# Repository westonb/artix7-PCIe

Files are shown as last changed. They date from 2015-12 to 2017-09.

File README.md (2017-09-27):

# artix7-PCIe
Originally designed for a SDR expansion card. Design includes breakout header, 2 general purpose buttons, and a SFP cage. 

Optimized for OSHPark 4 layer fab and home assembly. 

Design has been built but prototypes were killed by JTAG ground loop due to user error. Further work not certain, but please fork and feel free to contact for support.

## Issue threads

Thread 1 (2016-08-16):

was this board built?

aholtzma, 2016-08-16:
I see you sent this board off to fab. Was it built? Did you need to make any changes to make it work?

theocean154, 2016-12-01:
Im also interested to know if this worked, im working on a very similar board, basically a stripped down AC701 with just the pcie, Ethernet, DDR, SD, and jtag, and could use your board as a reference.

theocean154, 2016-12-01:
https://oshpark.com/shared_projects/hLGqMXZK

westonb, 2016-12-11:
Board was built, before I could finish verifying everything I killed the FPGA with a JTAG ground loop. Future version I am going to add some buffers / protection on the JTAG lines. Have not had time to make more boards.

You are probably going to need to add more PCB layers for DRAM.

Closed 2016-12-11.

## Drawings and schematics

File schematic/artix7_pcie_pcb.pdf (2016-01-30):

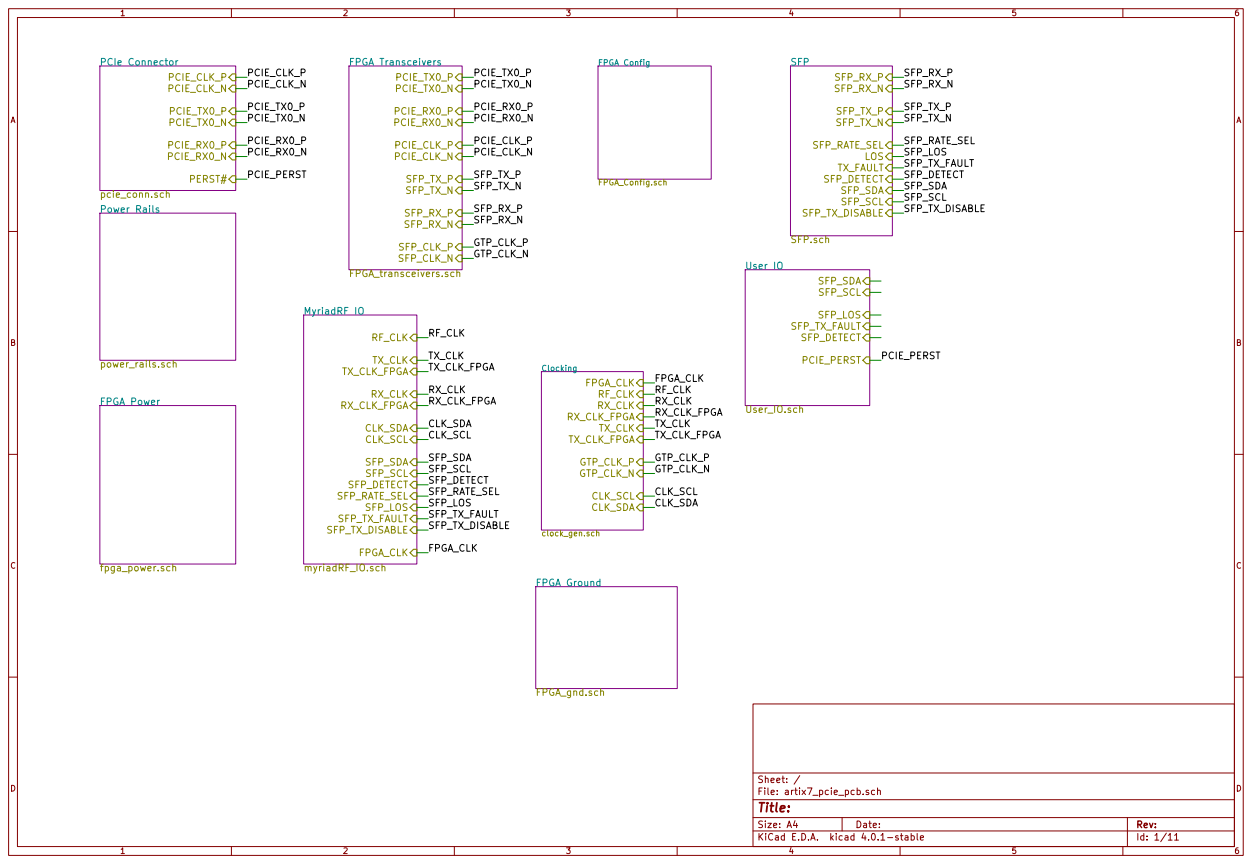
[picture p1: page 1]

PERST# Power Rails power_rails.sch
pcie_conn.sch

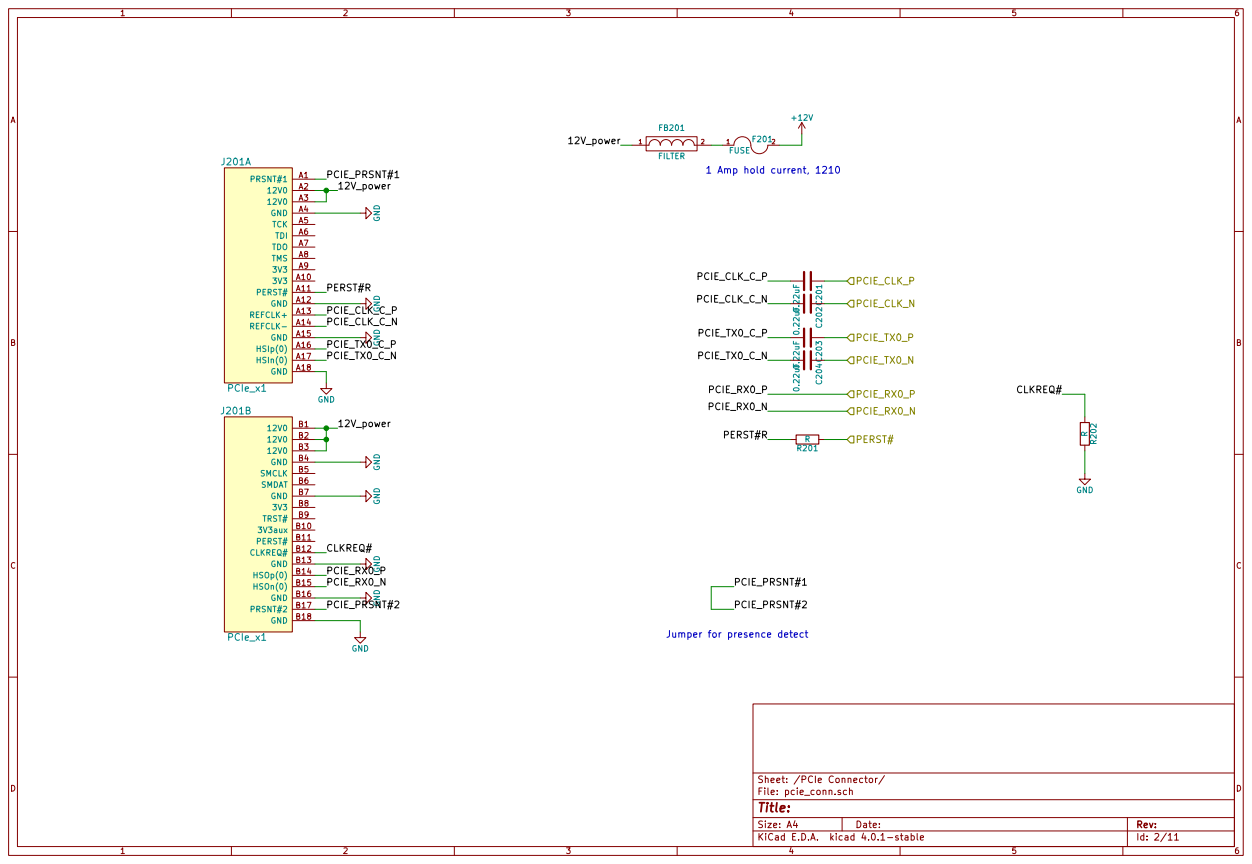
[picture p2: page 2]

File: pcie_conn.sch Sheet: /PCIe Connector/

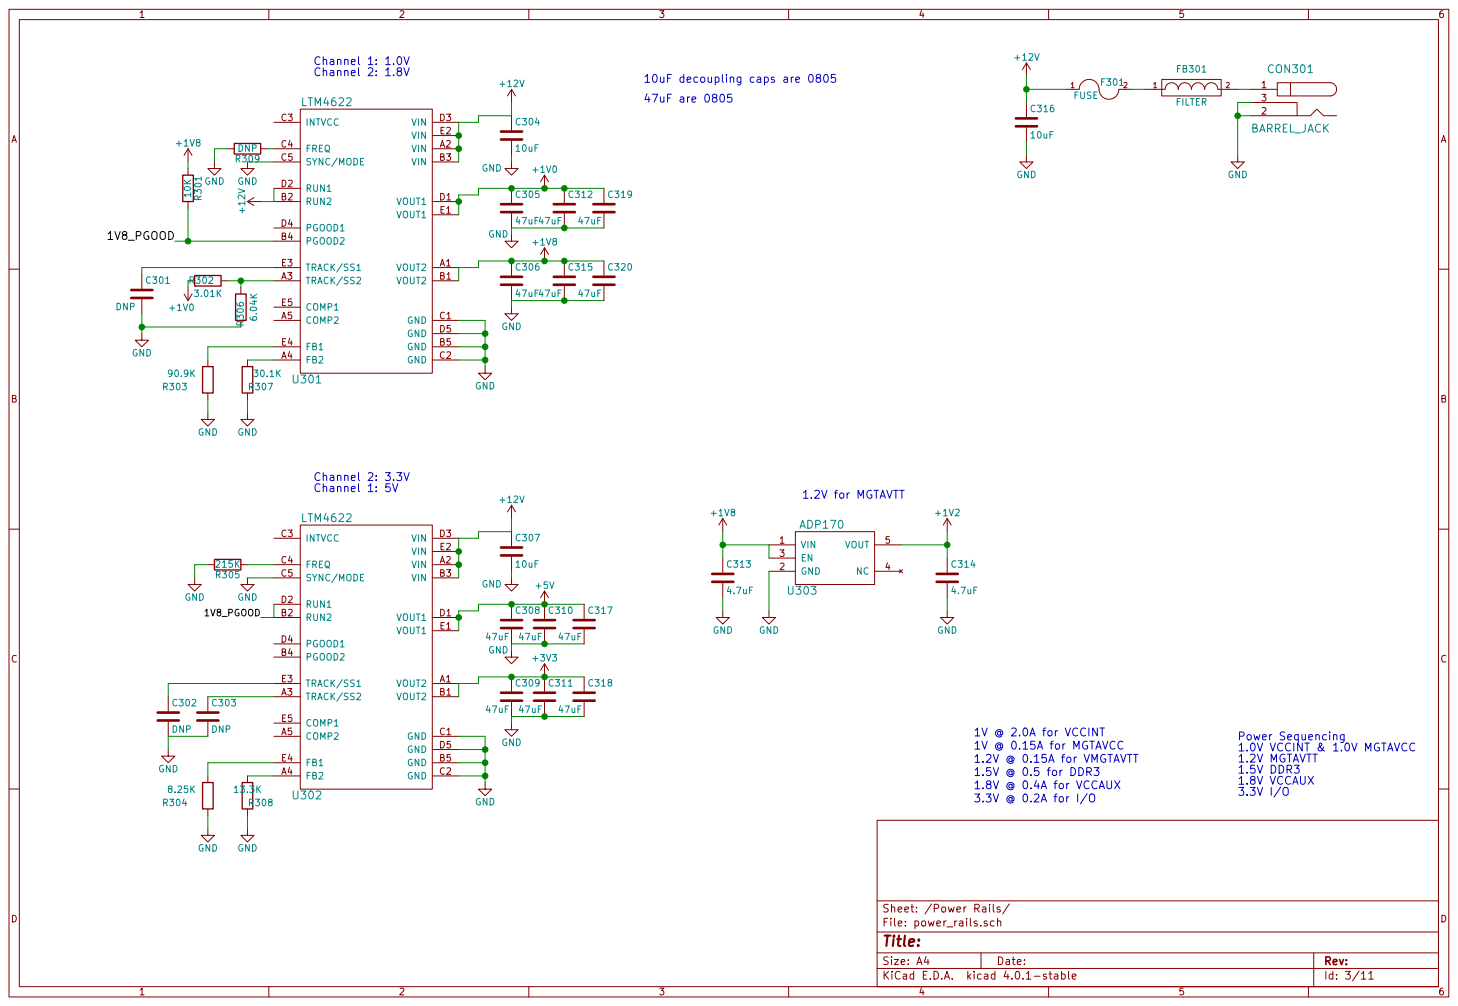
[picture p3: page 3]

File: power_rails.sch Sheet: /Power Rails/
Id: 3/11 Title:

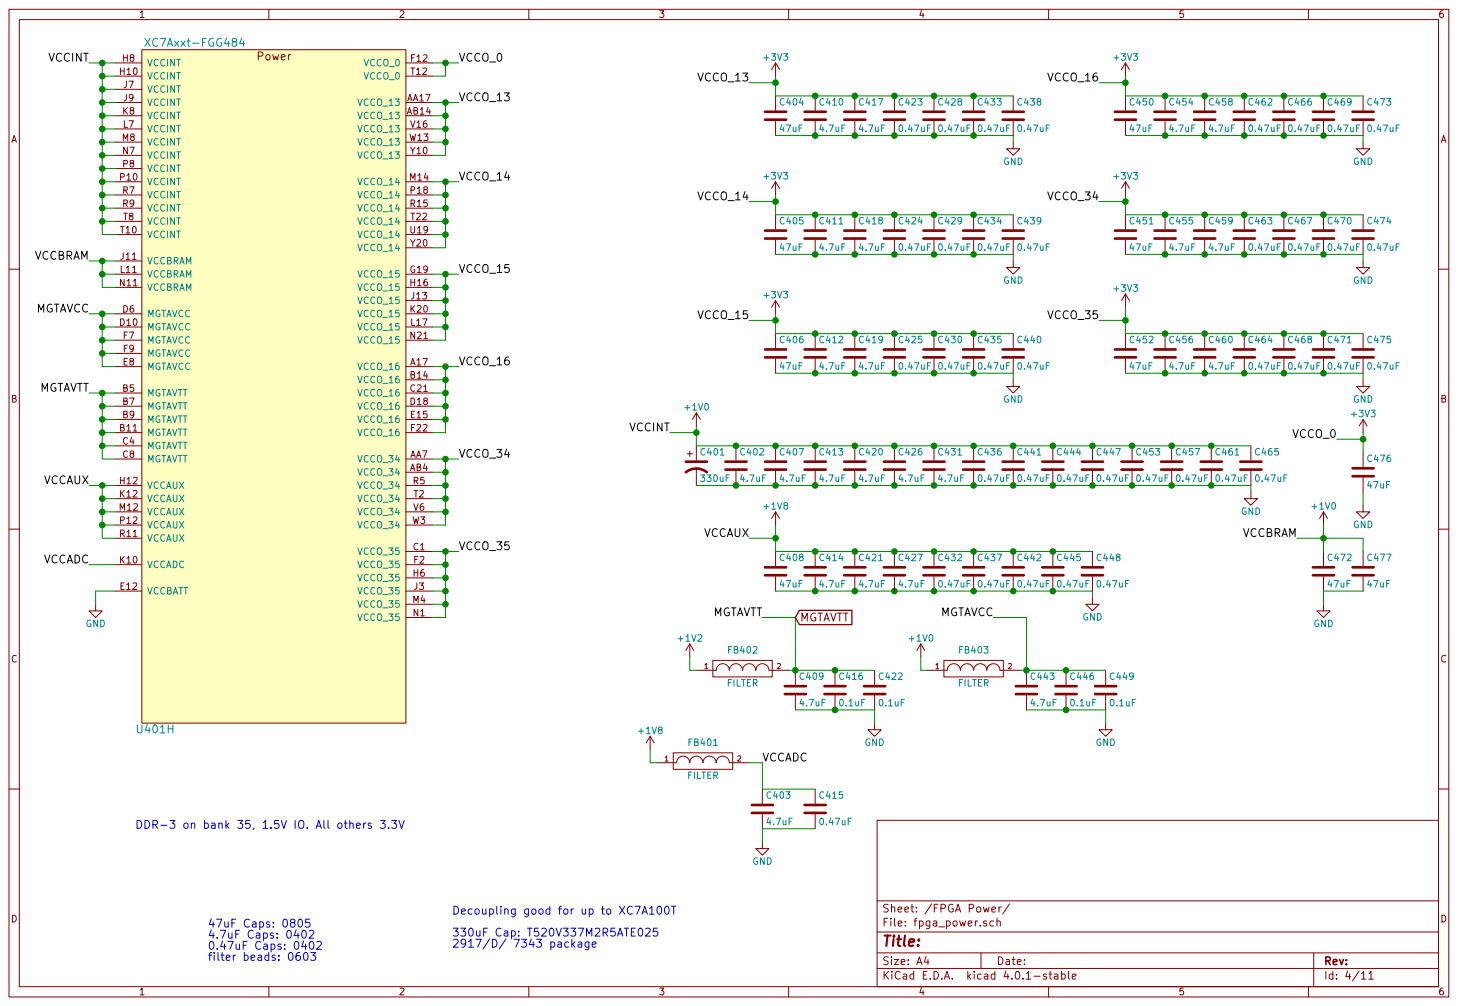
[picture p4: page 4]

0.47uF Decoupling good for up to XC7A100T

DDR-3 on bank 35, 1.5V IO. All others 3.3V

File: fpga_power.sch Sheet: /FPGA Power/
Id: 4/11 Title:

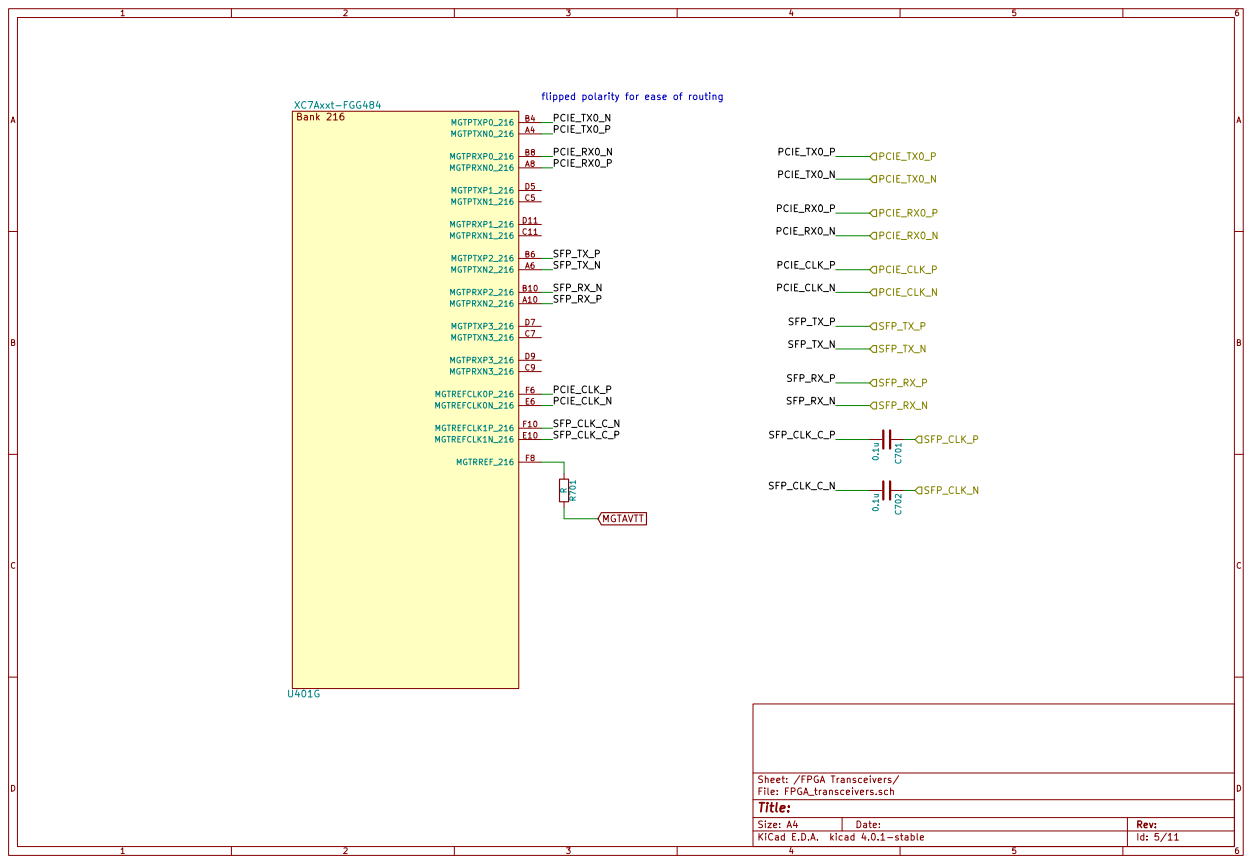
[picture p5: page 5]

flipped polarity for ease of routing

File: FPGA_transceivers.sch Sheet: /FPGA Transceivers/

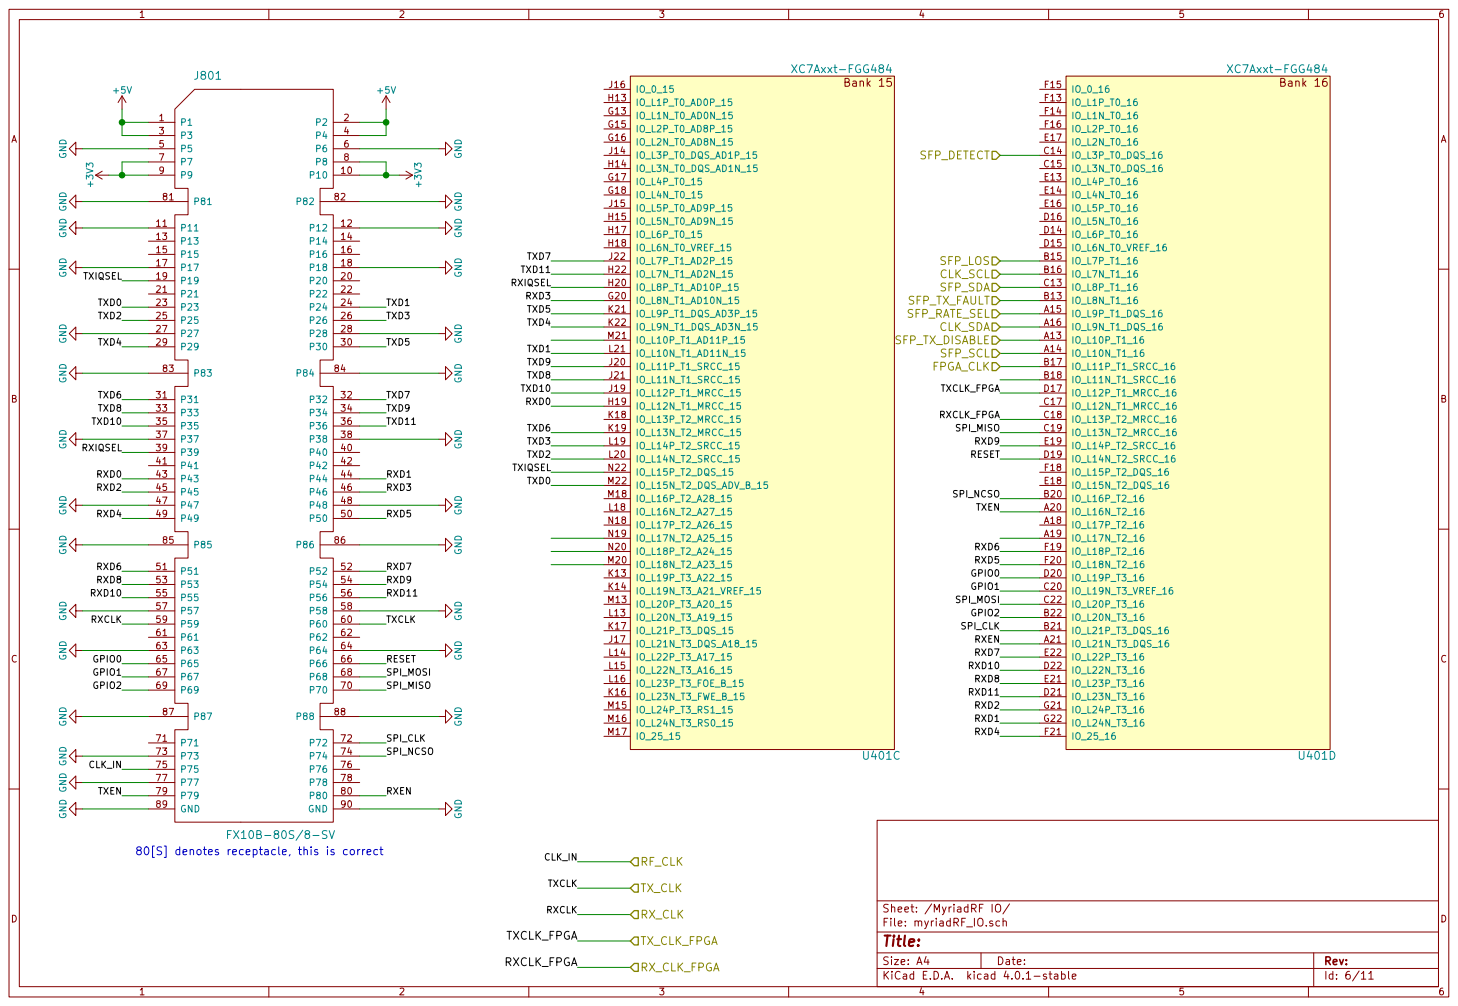
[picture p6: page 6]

80[S] denotes receptacle, this is correct

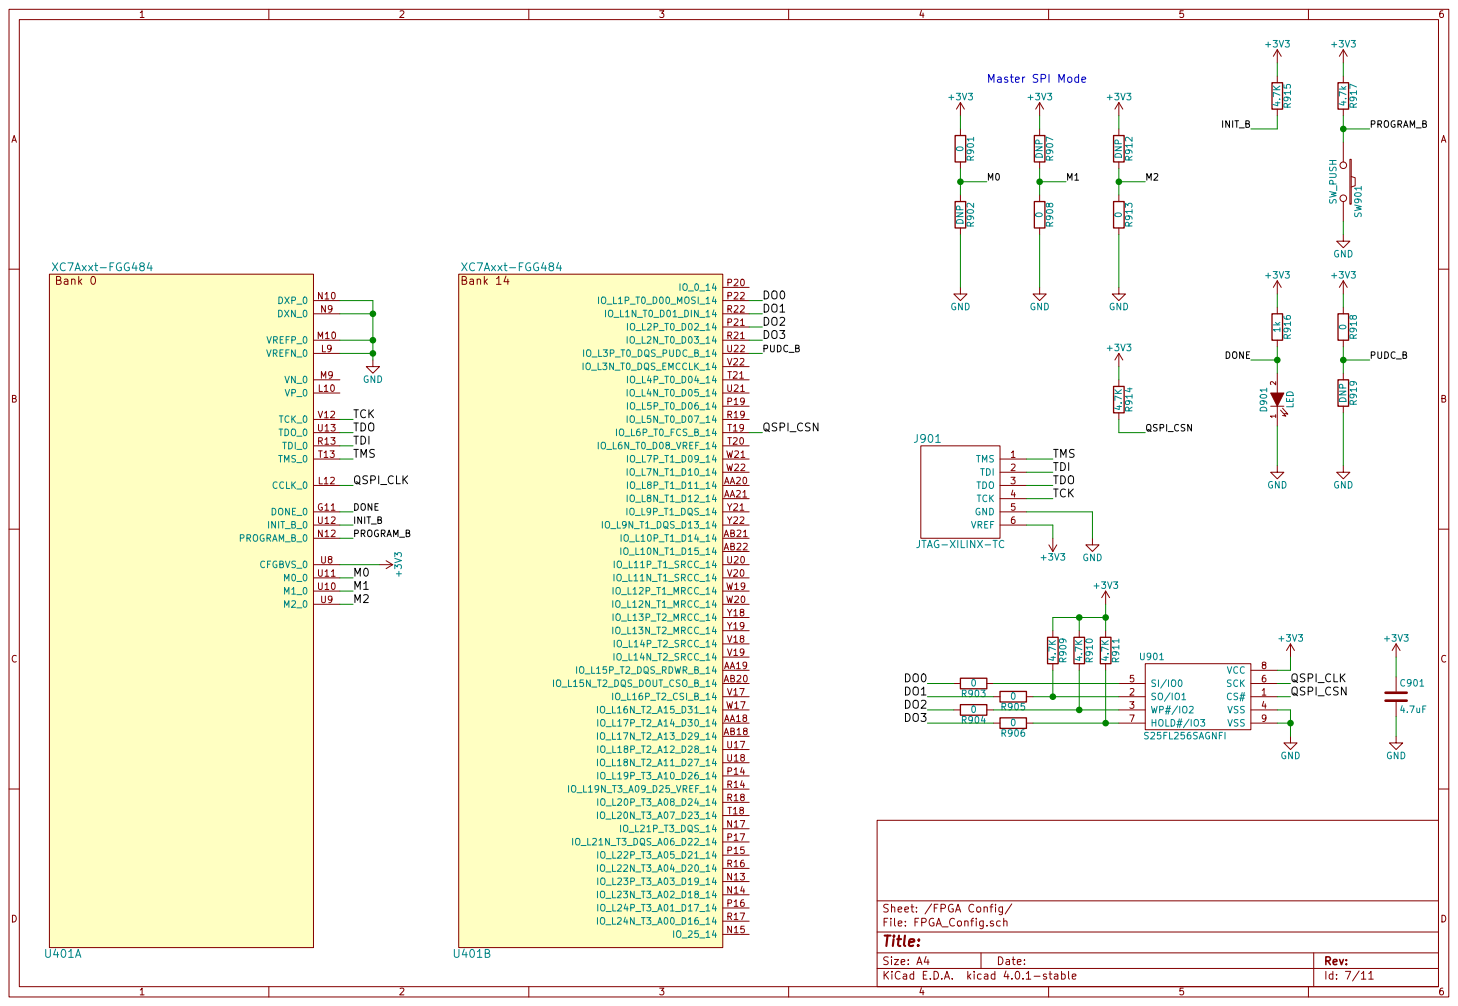
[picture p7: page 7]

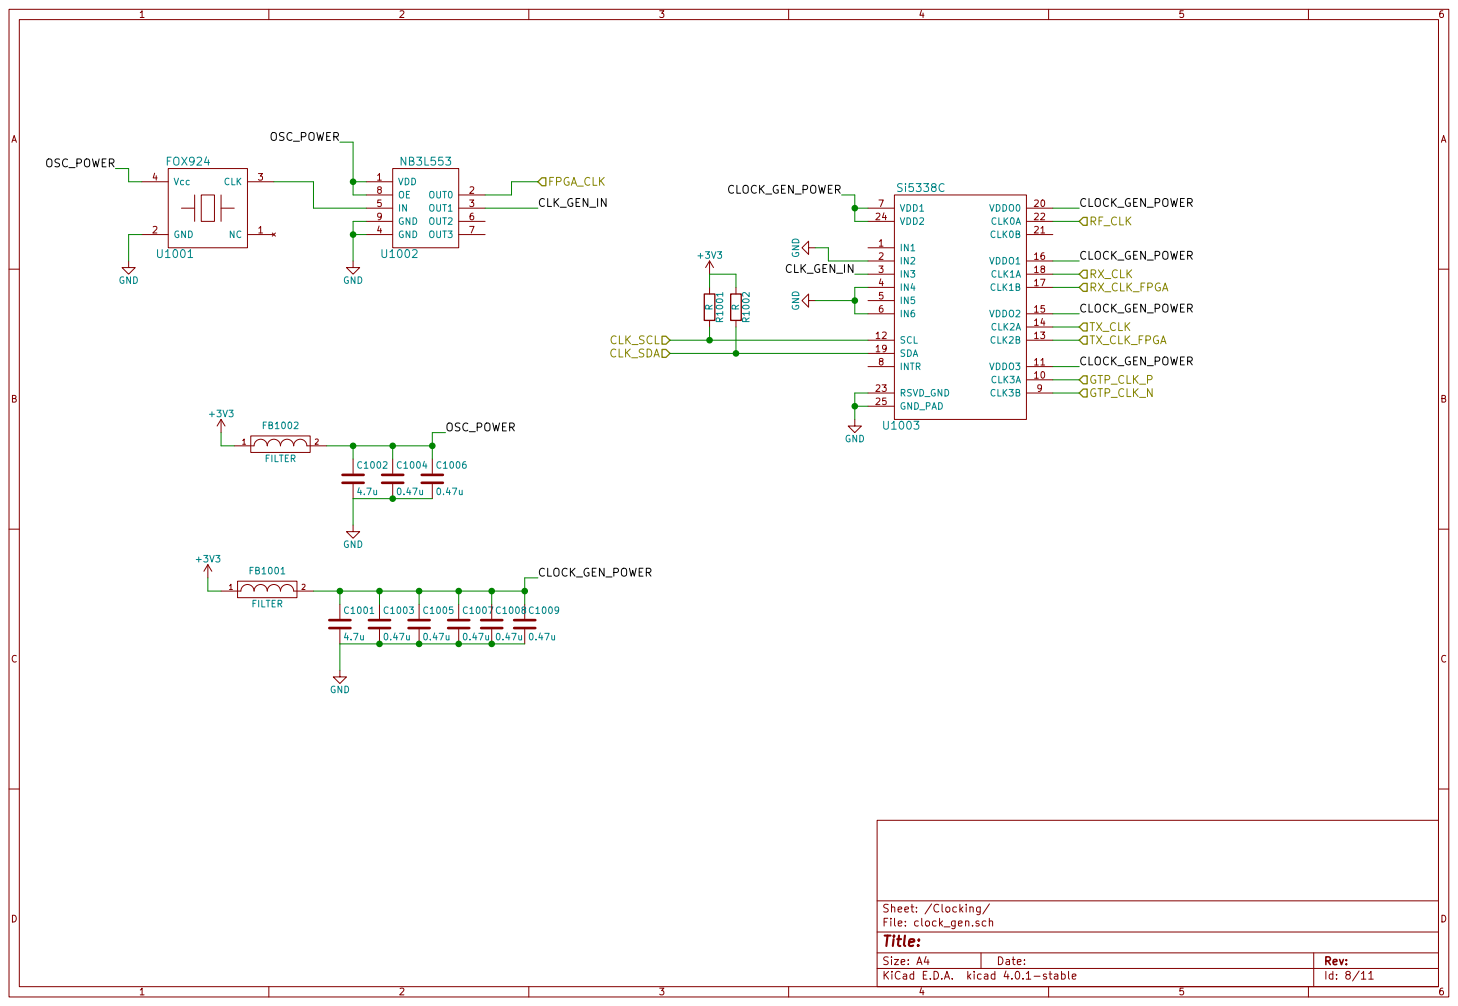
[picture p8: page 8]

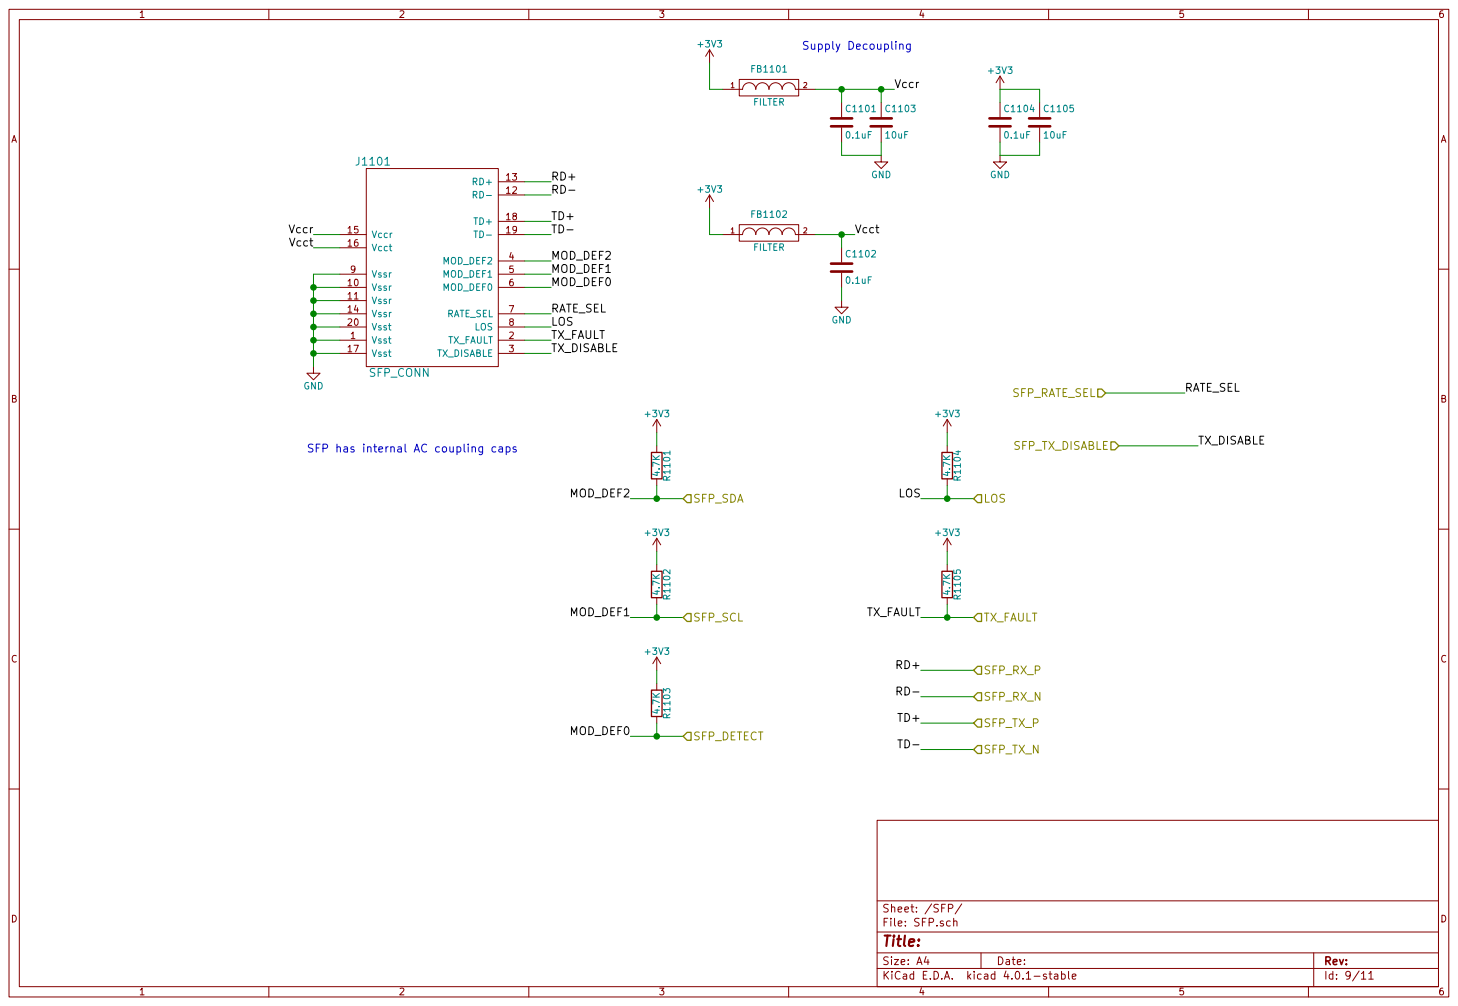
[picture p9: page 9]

Id: 9/11 Title: File: SFP.sch Sheet: /SFP/

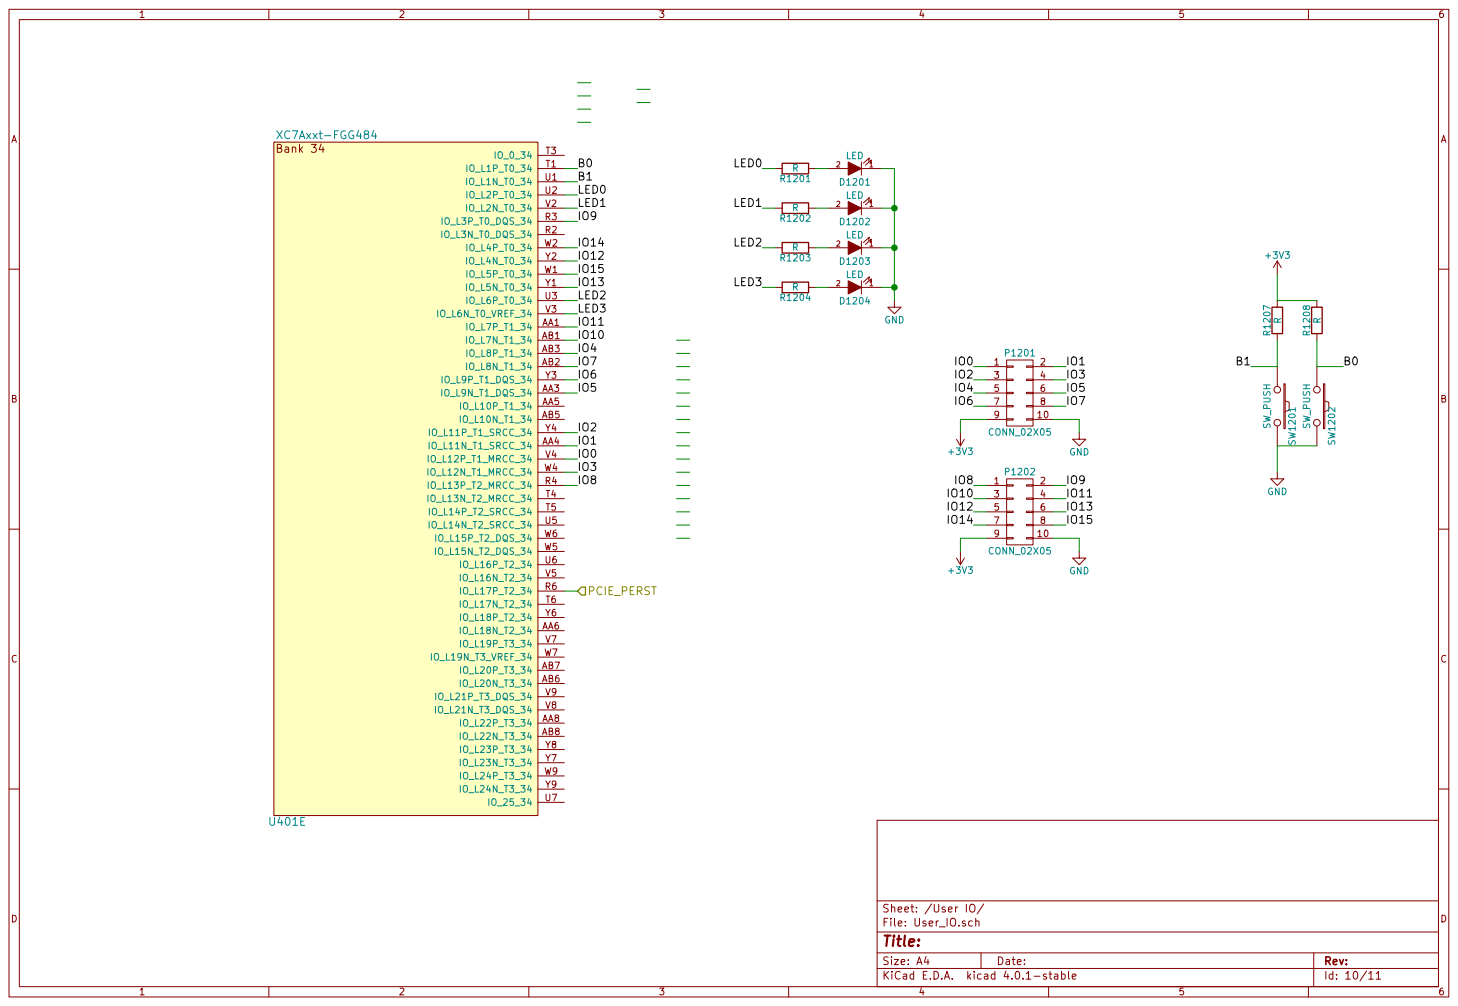
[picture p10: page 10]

File: User_IO.sch Sheet: /User IO/

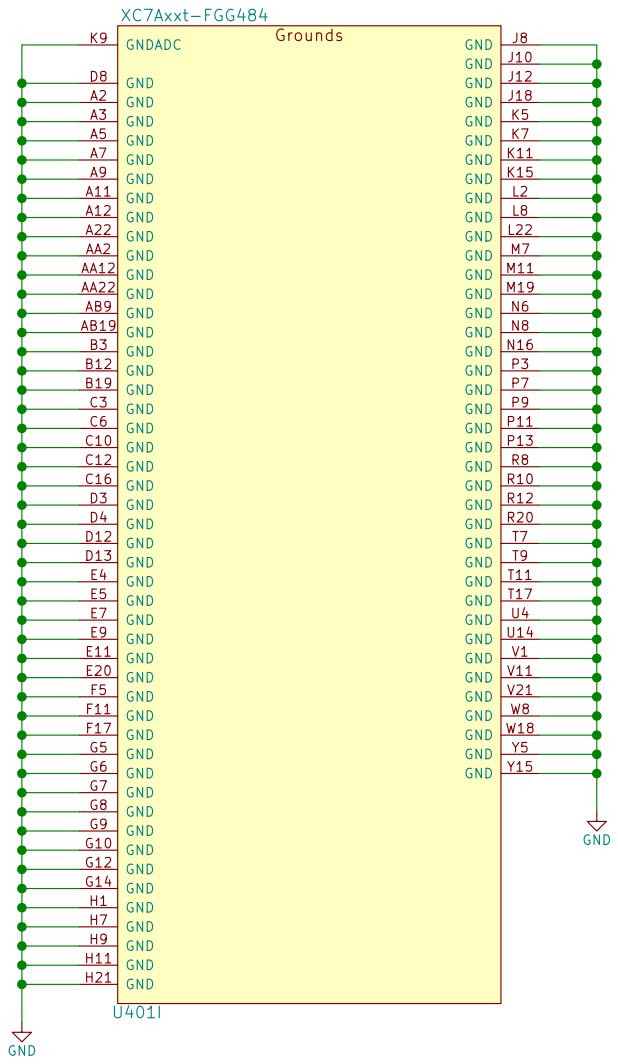
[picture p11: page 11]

File: FPGA_gnd.sch Sheet: /FPGA Ground/

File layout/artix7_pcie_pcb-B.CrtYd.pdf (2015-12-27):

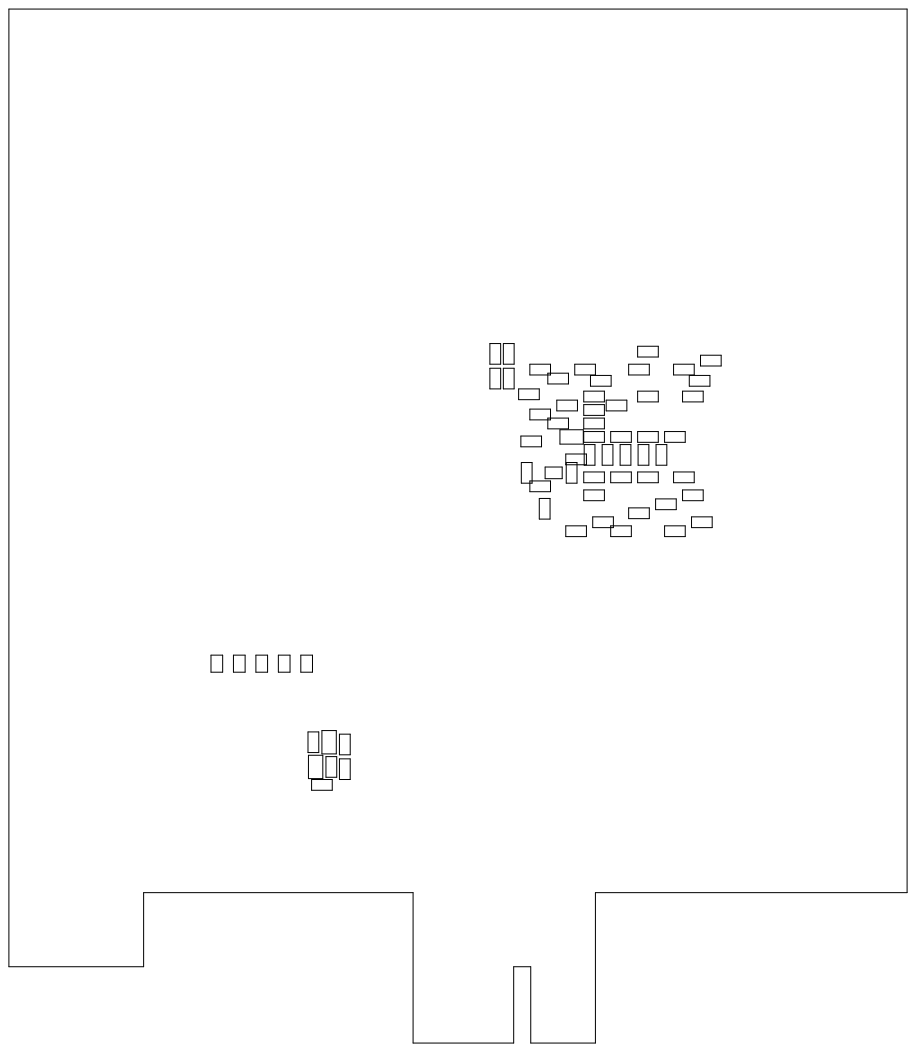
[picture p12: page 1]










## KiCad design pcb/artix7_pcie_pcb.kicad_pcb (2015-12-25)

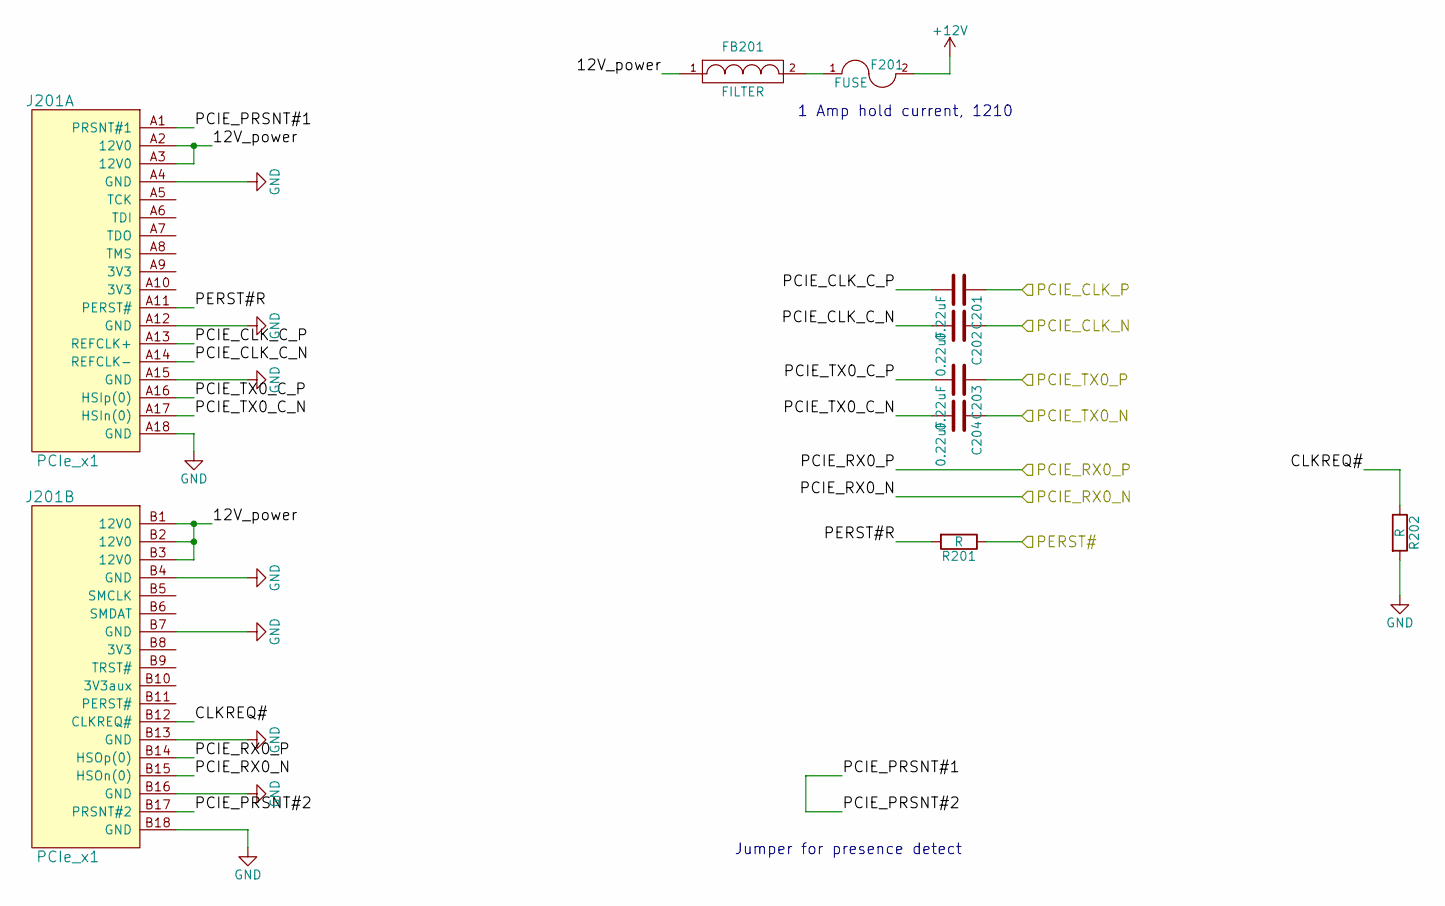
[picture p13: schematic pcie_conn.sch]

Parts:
C201, C202, C203, C204: 0.22uF; C_0402
F201: FUSE; SMD-0805
FB201: FILTER; L_0603
J201: PCIe_x1; PCIe_1x
R201, R202: R; R_0402

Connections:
+12V: F201.2; also elsewhere on the board
/FPGA Transceivers/PCIE_CLK_N: C202.1; also elsewhere on the board
/FPGA Transceivers/PCIE_CLK_P: C201.1; also elsewhere on the board
/FPGA Transceivers/PCIE_RX0_N: J201.B15 (HSOn(0)); also elsewhere on the board
/FPGA Transceivers/PCIE_RX0_P: J201.B14 (HSOp(0)); also elsewhere on the board
/FPGA Transceivers/PCIE_TX0_N: C204.1; also elsewhere on the board
/FPGA Transceivers/PCIE_TX0_P: C203.1; also elsewhere on the board
/PCIe Connector/12V_power: FB201.1, J201.A2 (12V0), J201.A3 (12V0), J201.B1 (12V0), J201.B2 (12V0), J201.B3 (12V0)
/PCIe Connector/CLKREQ#: J201.B12 (CLKREQ#), R202.1
/PCIe Connector/PCIE_CLK_C_N: C202.2, J201.A14 (REFCLK-)
/PCIe Connector/PCIE_CLK_C_P: C201.2, J201.A13 (REFCLK+)
/PCIe Connector/PCIE_PRSNT#1: J201.A1 (PRSNT#1), J201.B17 (PRSNT#2)
/PCIe Connector/PCIE_TX0_C_N: C204.2, J201.A17 (HSIn(0))
/PCIe Connector/PCIE_TX0_C_P: C203.2, J201.A16 (HSIp(0))
/PCIe Connector/PERST#R: J201.A11 (PERST#), R201.2
/User IO/PCIE_PERST: R201.1; also elsewhere on the board
GND: J201.A4 (GND), J201.A12 (GND), J201.A15 (GND), J201.A18 (GND), J201.B4 (GND), J201.B7 (GND), J201.B13 (GND), J201.B16 (GND), J201.B18 (GND), R202.2; also elsewhere on the board
unnamed: F201.1, FB201.2

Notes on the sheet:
Jumper for presence detect
1 Amp hold current, 1210

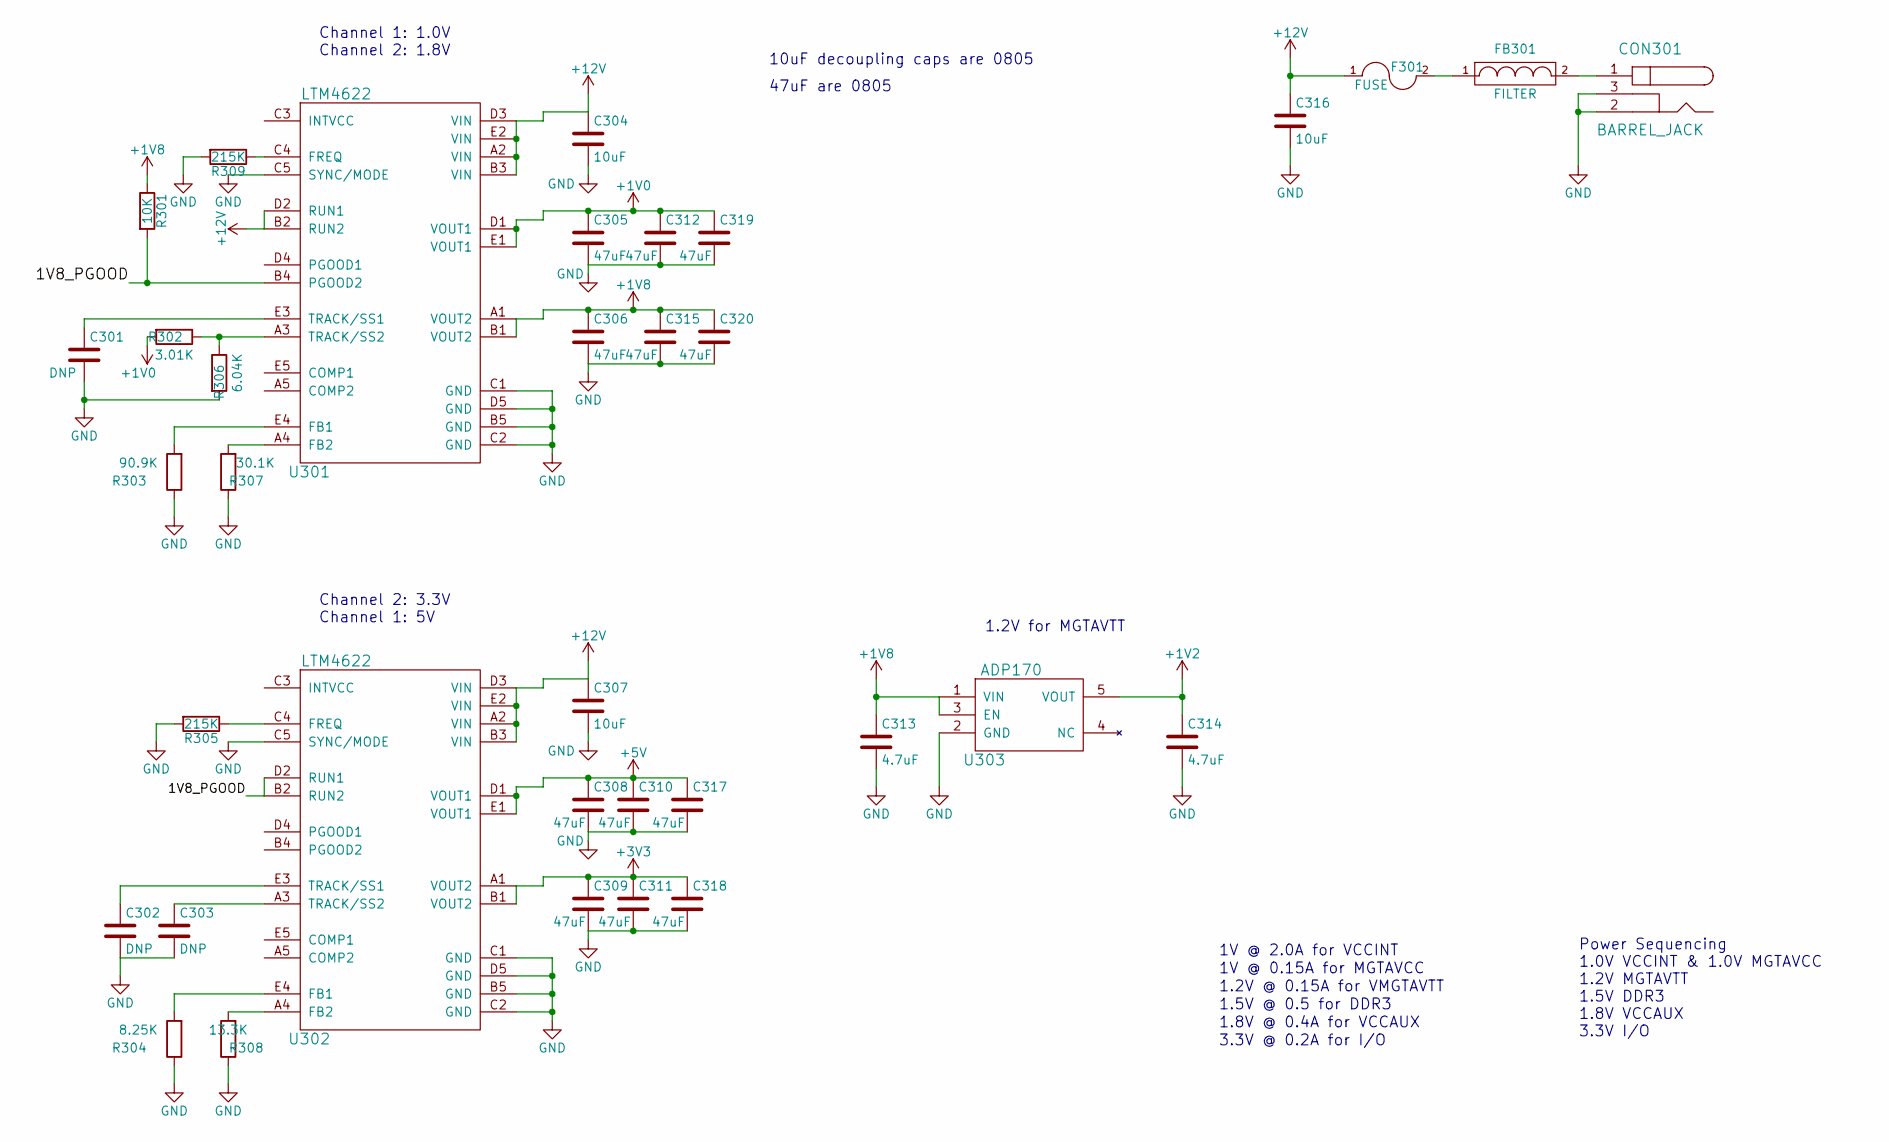
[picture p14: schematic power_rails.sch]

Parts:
C301, C302, C303: DNP; C_0402
C304, C307, C316: 10uF; C_0805
C305, C306, C308, C309, C310, C311, C312, C315, C317, C318, C319, C320: 47uF; C_0805
C313, C314: 4.7uF; C_0402
CON301: BARREL_JACK; DC_2.1mm_PJ-202A
F301: FUSE; SMD-0805
FB301: FILTER; L_0603
R301: 10K; R_0402
R302: 3.01K; R_0402
R303: 90.9K; R_0402
R304: 8.25K; R_0402
R305, R309: 215K; R_0402
R306: 6.04K; R_0402
R307: 30.1K; R_0402
R308: 13.3K; R_0402
U301, U302: LTM4622; LGA25_6_25x6_25
U303: ADP170; TSOT-23-5

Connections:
+1V0: C305.1, C312.1, C319.1, R302.2, U301.D1 (VOUT1), U301.E1 (VOUT1); also elsewhere on the board
+1V2: C314.1, U303.5 (VOUT); also elsewhere on the board
+1V8: C306.1, C313.1, C315.1, C320.1, R301.1, U301.A1 (VOUT2), U301.B1 (VOUT2), U303.1 (VIN), U303.3 (EN); also elsewhere on the board
+3V3: C309.1, C311.1, C318.1, U302.A1 (VOUT2), U302.B1 (VOUT2); also elsewhere on the board
+5V: C308.1, C310.1, C317.1, U302.D1 (VOUT1), U302.E1 (VOUT1); also elsewhere on the board
+12V: C304.1, C307.1, C316.1, F301.1, U301.A2 (VIN), U301.B2 (RUN2), U301.B3 (VIN), U301.D2 (RUN1), U301.D3 (VIN), U301.E2 (VIN), U302.A2 (VIN), U302.B3 (VIN), U302.D3 (VIN), U302.E2 (VIN); also elsewhere on the board
/Power Rails/1V8_PGOOD: R301.2, U301.B4 (PGOOD2), U302.B2 (RUN2), U302.D2 (RUN1)
GND: C301.2, C302.2, C303.2, C304.2, C305.2, C306.2, C307.2, C308.2, C309.2, C310.2, C311.2, C312.2, C313.2, C314.2, C315.2, C316.2, C317.2, C318.2, C319.2, C320.2, CON301.2, CON301.3, R303.1, R304.1, R305.2, R306.2, R307.1, R308.1, R309.2, U301.B5 (GND), U301.C1 (GND), U301.C2 (GND), U301.C5 (SYNC/MODE), U301.D5 (GND), U302.B5 (GND), U302.C1 (GND), U302.C2 (GND), U302.C5 (SYNC/MODE), U302.D5 (GND), U303.2 (GND); also elsewhere on the board
unnamed: C301.1, U301.E3 (TRACK/SS1)
unnamed: C302.1, U302.E3 (TRACK/SS1)
unnamed: C303.1, U302.A3 (TRACK/SS2)
unnamed: CON301.1, FB301.2
unnamed: F301.2, FB301.1
unnamed: R302.1, R306.1, U301.A3 (TRACK/SS2)
unnamed: R303.2, U301.E4 (FB1)
unnamed: R304.2, U302.E4 (FB1)
unnamed: R305.1, U302.C4 (FREQ)
unnamed: R307.2, U301.A4 (FB2)
unnamed: R308.2, U302.A4 (FB2)
unnamed: R309.1, U301.C4 (FREQ)

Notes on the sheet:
1.5V @ 0.5 for DDR3
1V @ 2.0A for VCCINT
1.2V @ 0.15A for VMGTAVTT
1.8V @ 0.4A for VCCAUX
3.3V @ 0.2A for I/O
1V @ 0.15A for MGTAVCC
Power Sequencing 1.0V VCCINT & 1.0V MGTAVCC 1.2V MGTAVTT 1.5V DDR3 1.8V VCCAUX 3.3V I/O
Channel 1: 1.0V Channel 2: 1.8V
1.2V for MGTAVTT
Channel 2: 3.3V Channel 1: 5V
10uF decoupling caps are 0805
47uF are 0805

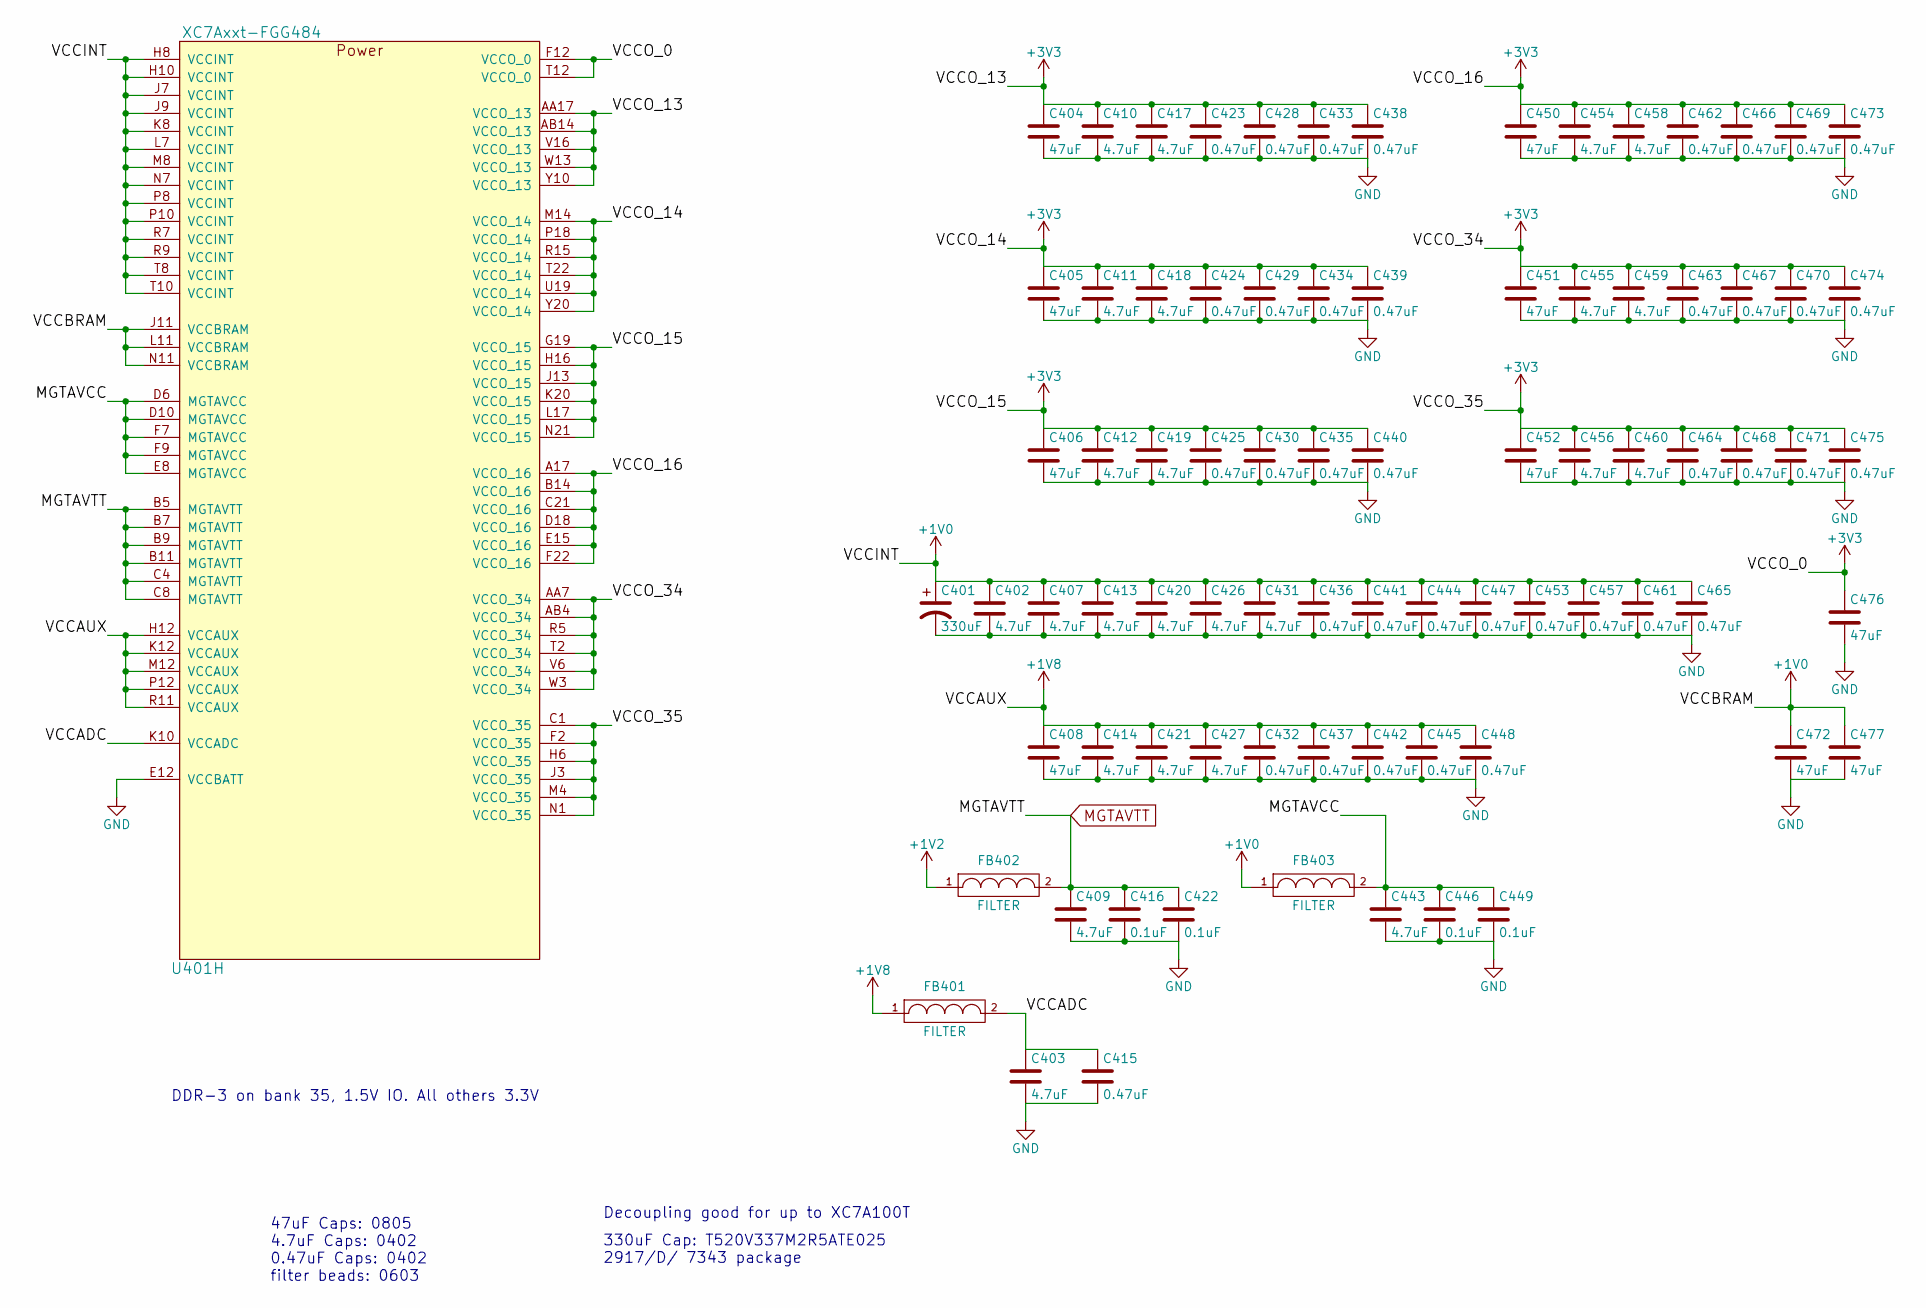
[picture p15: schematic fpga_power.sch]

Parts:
C401: 330uF; TantalC_SizeD_EIA-7343
C402, C403, C407, C409, C410, C411, C412, C413, C414, C417, C418, C419, C420, C421, C426, C427, C431, C443, C454, C455, C456, C458, C459, C460: 4.7uF; 0402_in_grid
C404, C405, C406, C408, C450, C451, C452, C472, C476, C477: 47uF; C_0805
C415, C423, C424, C425, C428, C429, C430, C432, C433, C434, C435, C436, C437, C438, C439, C440, C441, C442, C444, C445, C447, C448, C453, C457, C461, C462, C463, C464, C465, C466, C467, C468, C469, C470, C471, C473, C474, C475: 0.47uF; 0402_in_grid
C416, C422, C446, C449: 0.1uF; 0402_in_grid
FB401, FB402, FB403: FILTER; L_0603
U401: XC7Axxt-FGG484; BGA_484_22x22_FULLARRAY_1MM

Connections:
+1V0: C401.1, C402.1, C407.1, C413.1, C420.1, C426.1, C431.1, C436.1, C441.1, C444.1, C447.1, C453.1, C457.1, C461.1, C465.1, C472.1, C477.1, FB403.1, U401.H8 (VCCINT), U401.H10 (VCCINT), U401.J7 (VCCINT), U401.J9 (VCCINT), U401.J11 (VCCBRAM), U401.K8 (VCCINT), U401.L7 (VCCINT), U401.L11 (VCCBRAM), U401.M8 (VCCINT), U401.N7 (VCCINT), U401.N11 (VCCBRAM), U401.P8 (VCCINT), U401.P10 (VCCINT), U401.R7 (VCCINT), U401.R9 (VCCINT), U401.T8 (VCCINT), U401.T10 (VCCINT); also elsewhere on the board
+1V2: FB402.1; also elsewhere on the board
+1V8: C408.1, C414.1, C421.1, C427.1, C432.1, C437.1, C442.1, C445.1, C448.1, FB401.1, U401.H12 (VCCAUX), U401.K12 (VCCAUX), U401.M12 (VCCAUX), U401.P12 (VCCAUX), U401.R11 (VCCAUX); also elsewhere on the board
+3V3: C404.1, C405.1, C406.1, C410.1, C411.1, C412.1, C417.1, C418.1, C419.1, C423.1, C424.1, C425.1, C428.1, C429.1, C430.1, C433.1, C434.1, C435.1, C438.1, C439.1, C440.1, C450.1, C451.1, C452.1, C454.1, C455.1, C456.1, C458.1, C459.1, C460.1, C462.1, C463.1, C464.1, C466.1, C467.1, C468.1, C469.1, C470.1, C471.1, C473.1, C474.1, C475.1, C476.1, U401.A17 (VCCO_16), U401.AA7 (VCCO_34), U401.AA17 (VCCO_13), U401.AB4 (VCCO_34), U401.AB14 (VCCO_13), U401.B14 (VCCO_16), U401.C1 (VCCO_35), U401.C21 (VCCO_16), U401.D18 (VCCO_16), U401.E15 (VCCO_16), U401.F2 (VCCO_35), U401.F12 (VCCO_0), U401.F22 (VCCO_16), U401.G19 (VCCO_15), U401.H6 (VCCO_35), U401.H16 (VCCO_15), U401.J3 (VCCO_35), U401.J13 (VCCO_15), U401.K20 (VCCO_15), U401.L17 (VCCO_15), U401.M4 (VCCO_35), U401.M14 (VCCO_14), U401.N1 (VCCO_35), U401.N21 (VCCO_15), U401.P18 (VCCO_14), U401.R5 (VCCO_34), U401.R15 (VCCO_14), U401.T2 (VCCO_34), U401.T12 (VCCO_0), U401.T22 (VCCO_14), U401.U19 (VCCO_14), U401.V6 (VCCO_34), U401.V16 (VCCO_13), U401.W3 (VCCO_34), U401.W13 (VCCO_13), U401.Y10 (VCCO_13), U401.Y20 (VCCO_14); also elsewhere on the board
/FPGA Power/MGTAVCC: C443.1, C446.1, C449.1, FB403.2, U401.D6 (MGTAVCC), U401.D10 (MGTAVCC), U401.E8 (MGTAVCC), U401.F7 (MGTAVCC), U401.F9 (MGTAVCC)
/FPGA Power/VCCADC: C403.1, C415.1, FB401.2, U401.K10 (VCCADC)
GND: C401.2, C402.2, C403.2, C404.2, C405.2, C406.2, C407.2, C408.2, C409.2, C410.2, C411.2, C412.2, C413.2, C414.2, C415.2, C416.2, C417.2, C418.2, C419.2, C420.2, C421.2, C422.2, C423.2, C424.2, C425.2, C426.2, C427.2, C428.2, C429.2, C430.2, C431.2, C432.2, C433.2, C434.2, C435.2, C436.2, C437.2, C438.2, C439.2, C440.2, C441.2, C442.2, C443.2, C444.2, C445.2, C446.2, C447.2, C448.2, C449.2, C450.2, C451.2, C452.2, C453.2, C454.2, C455.2, C456.2, C457.2, C458.2, C459.2, C460.2, C461.2, C462.2, C463.2, C464.2, C465.2, C466.2, C467.2, C468.2, C469.2, C470.2, C471.2, C472.2, C473.2, C474.2, C475.2, C476.2, C477.2, U401.E12 (VCCBATT); also elsewhere on the board
MGTAVTT: C409.1, C416.1, C422.1, FB402.2, U401.B5 (MGTAVTT), U401.B7 (MGTAVTT), U401.B9 (MGTAVTT), U401.B11 (MGTAVTT), U401.C4 (MGTAVTT), U401.C8 (MGTAVTT); also elsewhere on the board

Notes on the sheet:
DDR-3 on bank 35, 1.5V IO. All others 3.3V
47uF Caps: 0805 4.7uF Caps: 0402 0.47uF Caps: 0402 filter beads: 0603
Decoupling good for up to XC7A100T
330uF Cap: T520V337M2R5ATE025 2917/D/ 7343 package

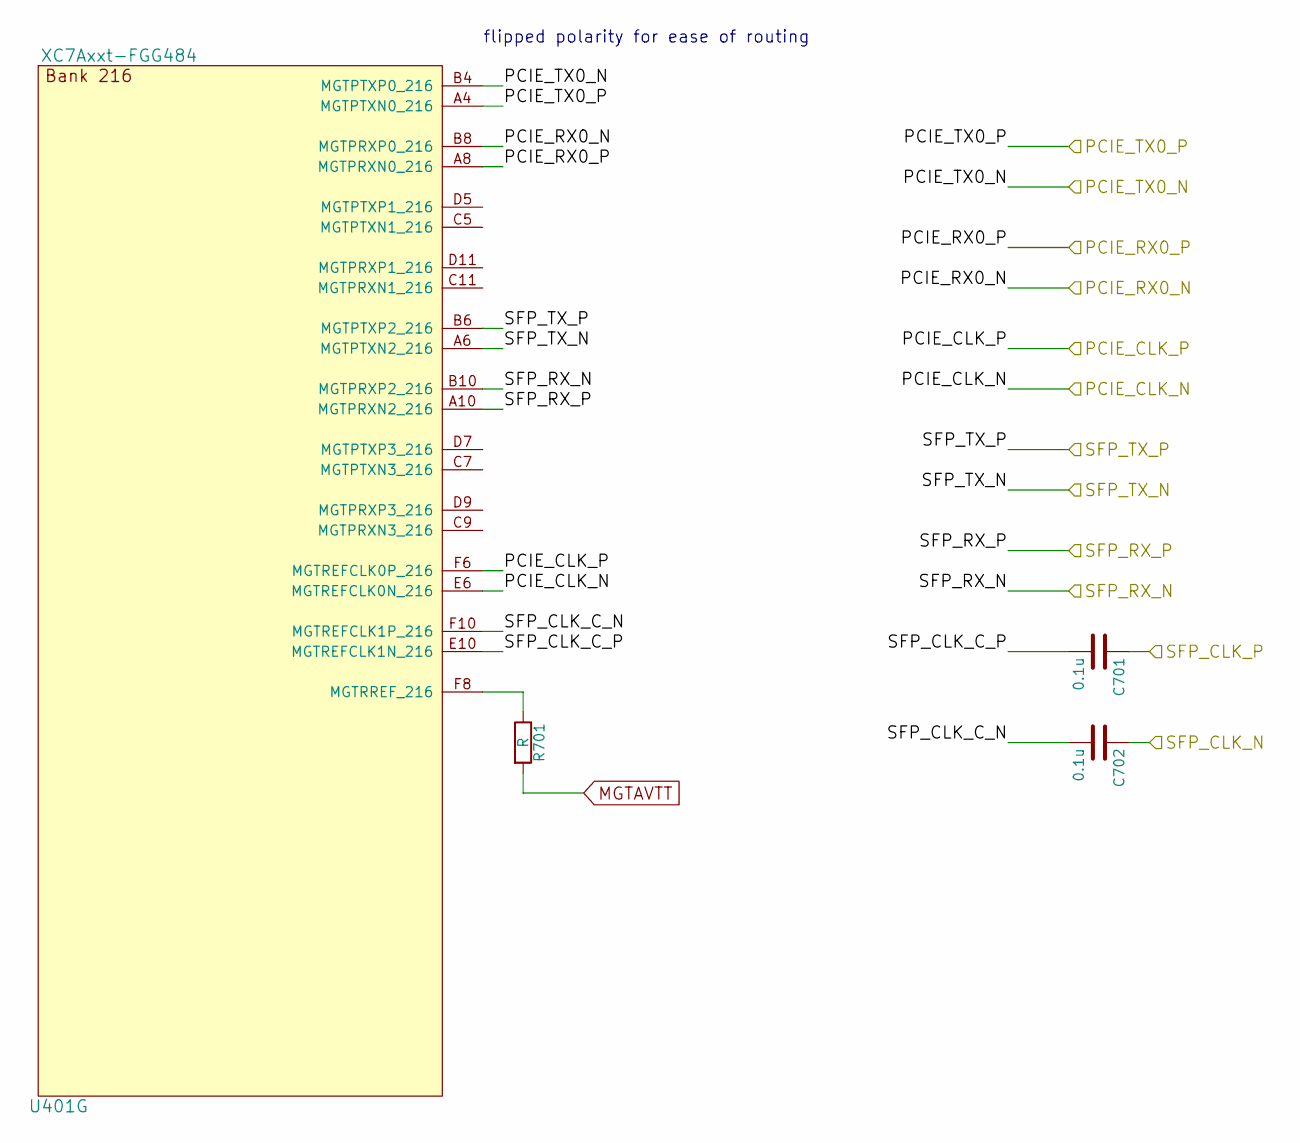
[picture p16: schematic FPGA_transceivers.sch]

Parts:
C701, C702: 0.1u; C_0402
R701: R; R_0402
U401: XC7Axxt-FGG484; BGA_484_22x22_FULLARRAY_1MM

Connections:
/Clocking/GTP_CLK_N: C702.1; also elsewhere on the board
/Clocking/GTP_CLK_P: C701.1; also elsewhere on the board
/FPGA Transceivers/PCIE_CLK_N: U401.E6 (MGTREFCLK0N_216); also elsewhere on the board
/FPGA Transceivers/PCIE_CLK_P: U401.F6 (MGTREFCLK0P_216); also elsewhere on the board
/FPGA Transceivers/PCIE_RX0_N: U401.B8 (MGTPRXP0_216); also elsewhere on the board
/FPGA Transceivers/PCIE_RX0_P: U401.A8 (MGTPRXN0_216); also elsewhere on the board
/FPGA Transceivers/PCIE_TX0_N: U401.B4 (MGTPTXP0_216); also elsewhere on the board
/FPGA Transceivers/PCIE_TX0_P: U401.A4 (MGTPTXN0_216); also elsewhere on the board
/FPGA Transceivers/SFP_CLK_C_N: C702.2, U401.F10 (MGTREFCLK1P_216)
/FPGA Transceivers/SFP_CLK_C_P: C701.2, U401.E10 (MGTREFCLK1N_216)
/FPGA Transceivers/SFP_RX_N: U401.B10 (MGTPRXP2_216); also elsewhere on the board
/FPGA Transceivers/SFP_RX_P: U401.A10 (MGTPRXN2_216); also elsewhere on the board
/FPGA Transceivers/SFP_TX_N: U401.A6 (MGTPTXN2_216); also elsewhere on the board
/FPGA Transceivers/SFP_TX_P: U401.B6 (MGTPTXP2_216); also elsewhere on the board
MGTAVTT: R701.2; also elsewhere on the board
unnamed: R701.1, U401.F8 (MGTRREF_216)

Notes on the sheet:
flipped polarity for ease of routing

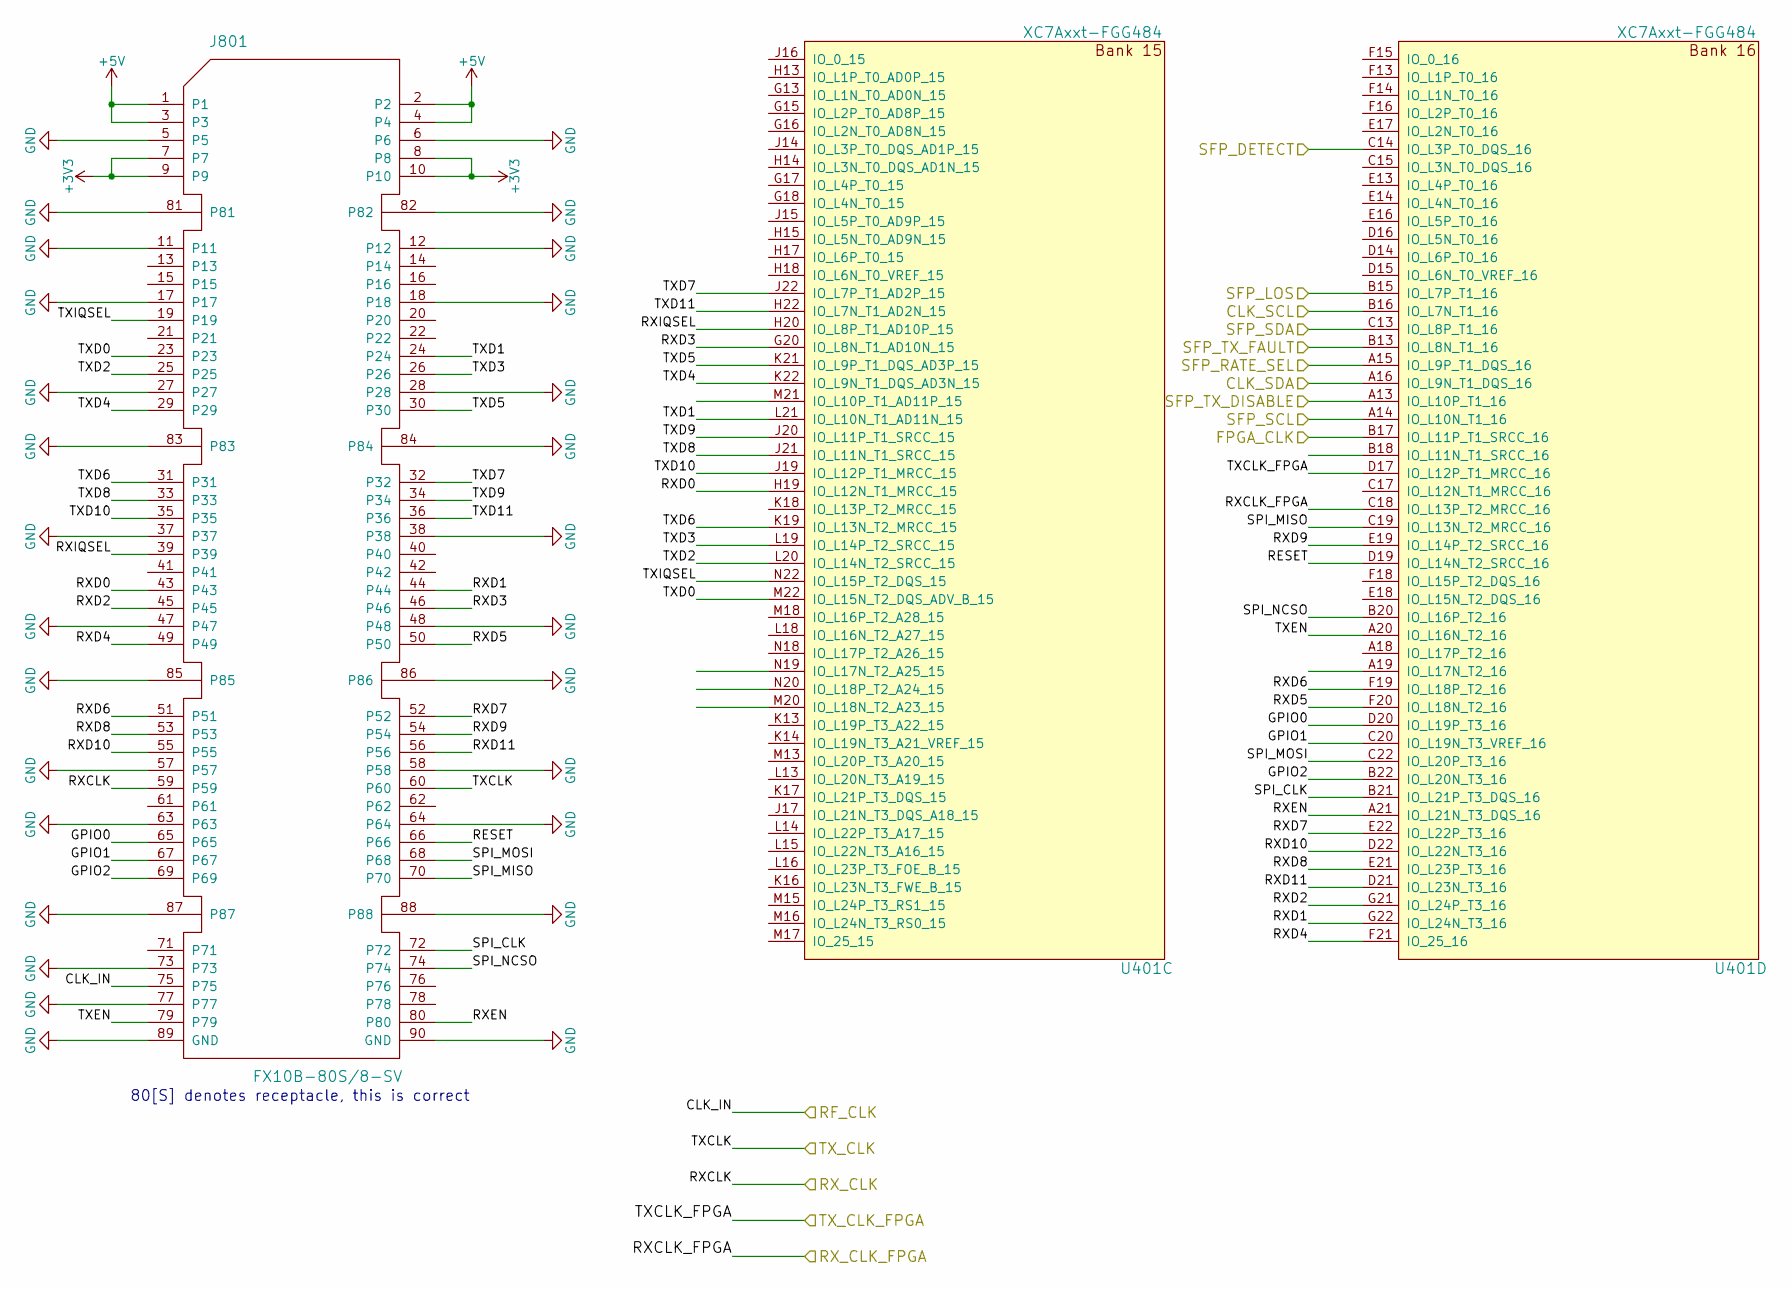
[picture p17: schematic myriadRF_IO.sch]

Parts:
J801: FX10B-80S/8-SV; FX10B_80S_8_SV
U401: XC7Axxt-FGG484; BGA_484_22x22_FULLARRAY_1MM

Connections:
+3V3: J801.7, J801.8, J801.9, J801.10; also elsewhere on the board
+5V: J801.1, J801.2, J801.3, J801.4; also elsewhere on the board
/Clocking/CLK_SCL: U401.B16 (IO_L7N_T1_16); also elsewhere on the board
/Clocking/CLK_SDA: U401.A16 (IO_L9N_T1_DQS_16); also elsewhere on the board
/Clocking/FPGA_CLK: U401.B17 (IO_L11P_T1_SRCC_16); also elsewhere on the board
/Clocking/RF_CLK: J801.75; also elsewhere on the board
/Clocking/RX_CLK: J801.59; also elsewhere on the board
/Clocking/RX_CLK_FPGA: U401.C18 (IO_L13P_T2_MRCC_16); also elsewhere on the board
/Clocking/TX_CLK: J801.60; also elsewhere on the board
/Clocking/TX_CLK_FPGA: U401.D17 (IO_L12P_T1_MRCC_16); also elsewhere on the board
/MyriadRF IO/GPIO0: J801.65, U401.D20 (IO_L19P_T3_16)
/MyriadRF IO/GPIO1: J801.67, U401.C20 (IO_L19N_T3_VREF_16)
/MyriadRF IO/GPIO2: J801.69, U401.B22 (IO_L20N_T3_16)
/MyriadRF IO/RESET: J801.66, U401.D19 (IO_L14N_T2_SRCC_16)
/MyriadRF IO/RXD0: J801.43, U401.H19 (IO_L12N_T1_MRCC_15)
/MyriadRF IO/RXD1: J801.44, U401.G22 (IO_L24N_T3_16)
/MyriadRF IO/RXD2: J801.45, U401.G21 (IO_L24P_T3_16)
/MyriadRF IO/RXD3: J801.46, U401.G20 (IO_L8N_T1_AD10N_15)
/MyriadRF IO/RXD4: J801.49, U401.F21 (IO_25_16)
/MyriadRF IO/RXD5: J801.50, U401.F20 (IO_L18N_T2_16)
/MyriadRF IO/RXD6: J801.51, U401.F19 (IO_L18P_T2_16)
/MyriadRF IO/RXD7: J801.52, U401.E22 (IO_L22P_T3_16)
/MyriadRF IO/RXD8: J801.53, U401.E21 (IO_L23P_T3_16)
/MyriadRF IO/RXD9: J801.54, U401.E19 (IO_L14P_T2_SRCC_16)
/MyriadRF IO/RXD10: J801.55, U401.D22 (IO_L22N_T3_16)
/MyriadRF IO/RXD11: J801.56, U401.D21 (IO_L23N_T3_16)
/MyriadRF IO/RXEN: J801.80, U401.A21 (IO_L21N_T3_DQS_16)
/MyriadRF IO/RXIQSEL: J801.39, U401.H20 (IO_L8P_T1_AD10P_15)
/MyriadRF IO/SFP_DETECT: U401.C14 (IO_L3P_T0_DQS_16); also elsewhere on the board
/MyriadRF IO/SFP_RATE_SEL: U401.A15 (IO_L9P_T1_DQS_16); also elsewhere on the board
/MyriadRF IO/SFP_SCL: U401.A14 (IO_L10N_T1_16); also elsewhere on the board
/MyriadRF IO/SFP_SDA: U401.C13 (IO_L8P_T1_16); also elsewhere on the board
/MyriadRF IO/SFP_TX_DISABLE: U401.A13 (IO_L10P_T1_16); also elsewhere on the board
/MyriadRF IO/SFP_TX_FAULT: U401.B13 (IO_L8N_T1_16); also elsewhere on the board
/MyriadRF IO/SPI_CLK: J801.72, U401.B21 (IO_L21P_T3_DQS_16)
/MyriadRF IO/SPI_MISO: J801.70, U401.C19 (IO_L13N_T2_MRCC_16)
/MyriadRF IO/SPI_MOSI: J801.68, U401.C22 (IO_L20P_T3_16)
/MyriadRF IO/SPI_NCSO: J801.74, U401.B20 (IO_L16P_T2_16)
/MyriadRF IO/TXD0: J801.23, U401.M22 (IO_L15N_T2_DQS_ADV_B_15)
/MyriadRF IO/TXD1: J801.24, U401.L21 (IO_L10N_T1_AD11N_15)
/MyriadRF IO/TXD2: J801.25, U401.L20 (IO_L14N_T2_SRCC_15)
/MyriadRF IO/TXD3: J801.26, U401.L19 (IO_L14P_T2_SRCC_15)
/MyriadRF IO/TXD4: J801.29, U401.K22 (IO_L9N_T1_DQS_AD3N_15)
/MyriadRF IO/TXD5: J801.30, U401.K21 (IO_L9P_T1_DQS_AD3P_15)
/MyriadRF IO/TXD6: J801.31, U401.K19 (IO_L13N_T2_MRCC_15)
/MyriadRF IO/TXD7: J801.32, U401.J22 (IO_L7P_T1_AD2P_15)
/MyriadRF IO/TXD8: J801.33, U401.J21 (IO_L11N_T1_SRCC_15)
/MyriadRF IO/TXD9: J801.34, U401.J20 (IO_L11P_T1_SRCC_15)
/MyriadRF IO/TXD10: J801.35, U401.J19 (IO_L12P_T1_MRCC_15)
/MyriadRF IO/TXD11: J801.36, U401.H22 (IO_L7N_T1_AD2N_15)
/MyriadRF IO/TXEN: J801.79, U401.A20 (IO_L16N_T2_16)
/MyriadRF IO/TXIQSEL: J801.19, U401.N22 (IO_L15P_T2_DQS_15)
/SFP/LOS: U401.B15 (IO_L7P_T1_16); also elsewhere on the board
GND: J801.5, J801.6, J801.11, J801.12, J801.17, J801.18, J801.27, J801.28, J801.37, J801.38, J801.47, J801.48, J801.57, J801.58, J801.63, J801.64, J801.73, J801.77, J801.81, J801.82, J801.83, J801.84, J801.85, J801.86, J801.87, J801.88, J801.89 (GND), J801.90 (GND); also elsewhere on the board

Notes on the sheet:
80[S] denotes receptacle, this is correct

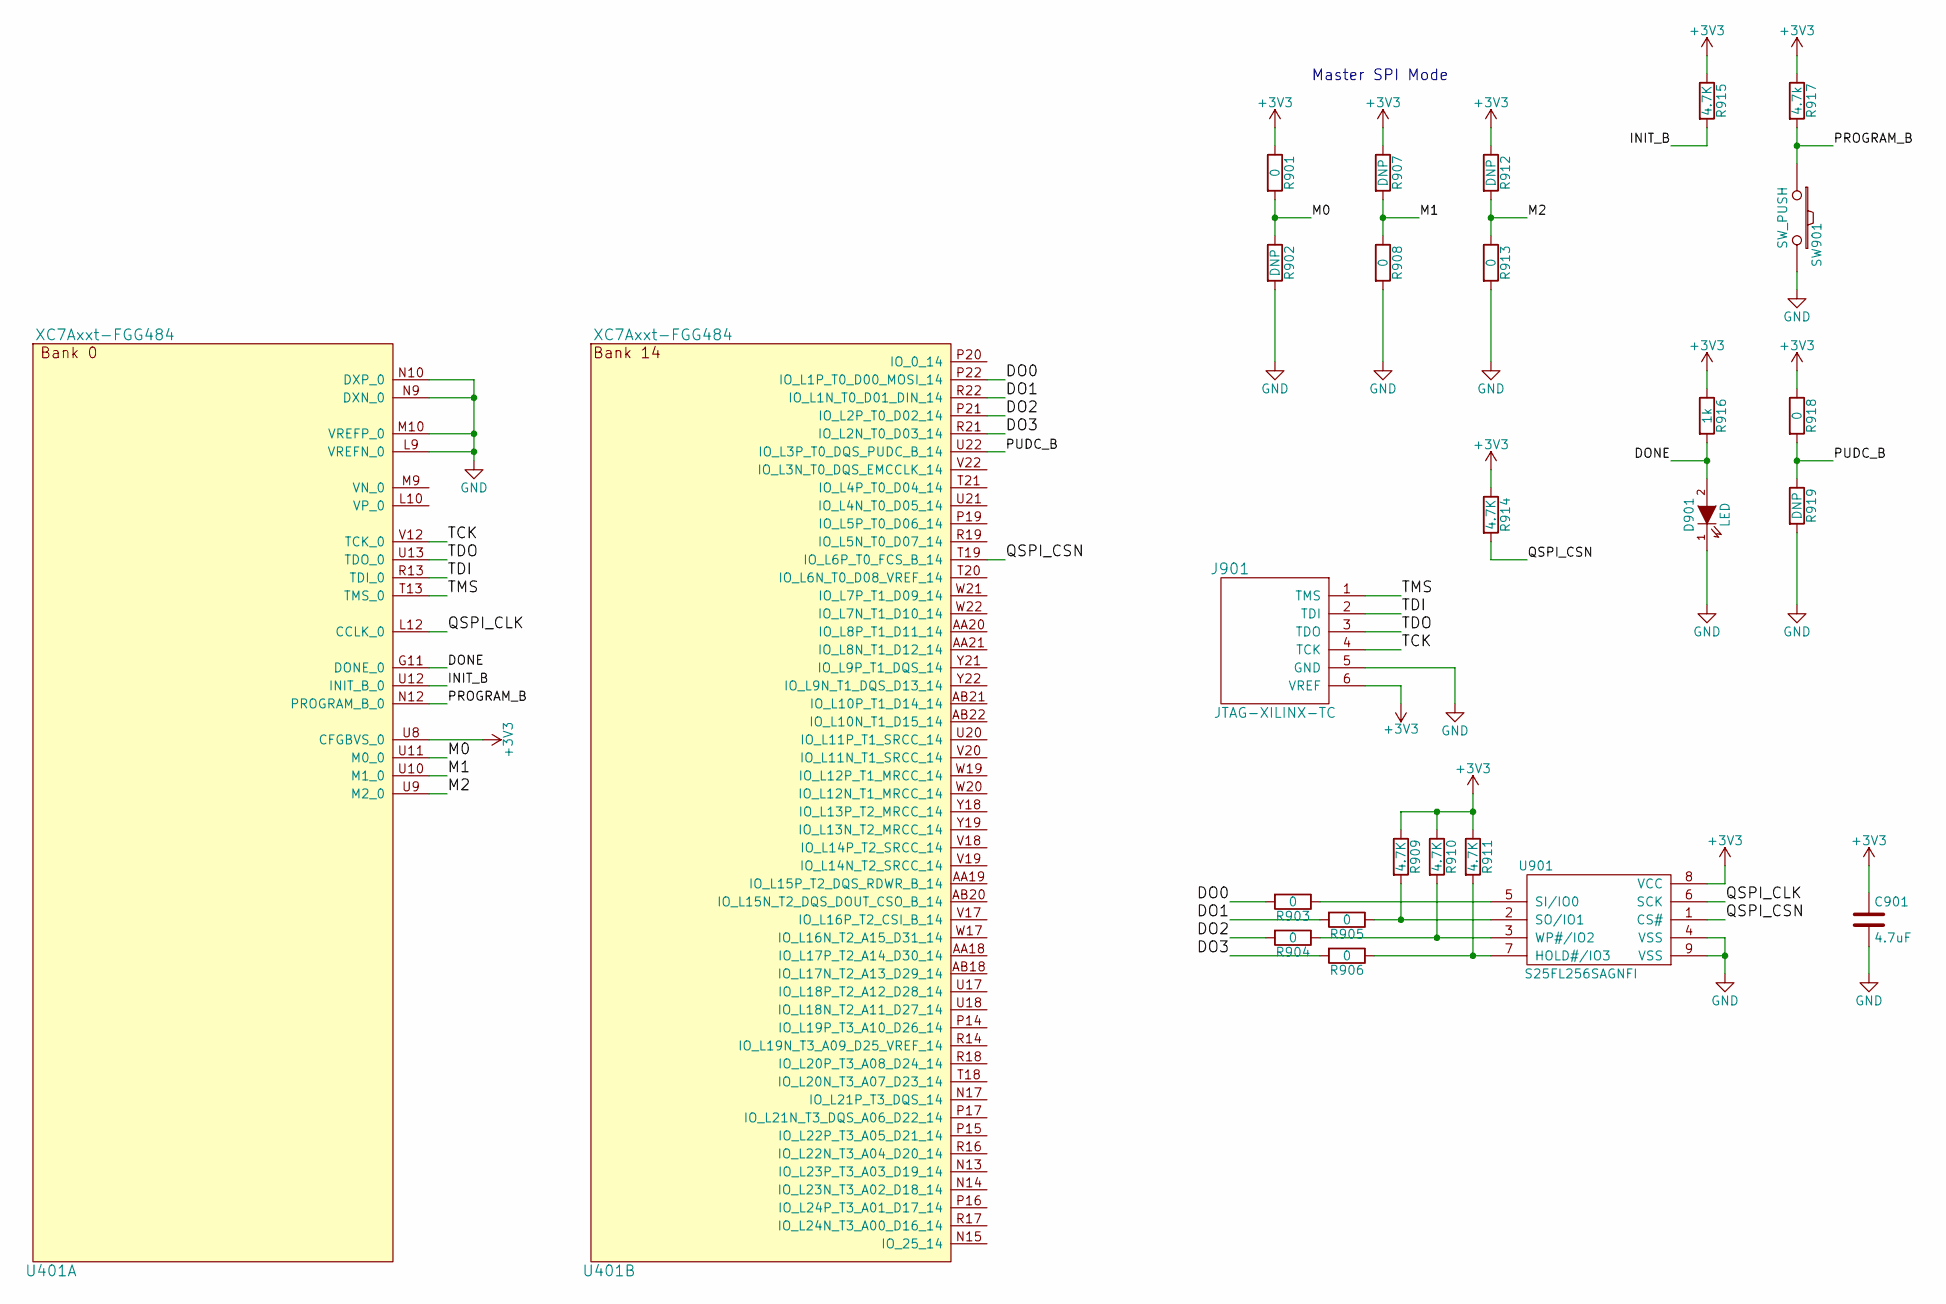
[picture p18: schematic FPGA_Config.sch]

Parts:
C901: 4.7uF; C_0402
D901: LED; LED-0805
J901: JTAG-XILINX-TC; TC2030-IDC-NL
R901, R903, R904, R905, R906, R908, R913, R918: 0; R_0402
R902, R907, R912, R919: DNP; R_0402
R909, R910, R911, R914, R915: 4.7K; R_0402
R916: 1k; R_0402
R917: 4.7k; R_0402
SW901: SW_PUSH; button-5mm
U401: XC7Axxt-FGG484; BGA_484_22x22_FULLARRAY_1MM
U901: S25FL256SAGNFI; 8-WSON_6x8_1.27mm

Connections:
+3V3: C901.1, J901.6 (VREF), R901.1, R907.1, R909.1, R910.1, R911.1, R912.1, R914.1, R915.1, R916.1, R917.1, R918.1, U401.U8 (CFGBVS_0), U901.8 (VCC); also elsewhere on the board
/FPGA Config/DO0: R903.2, U401.P22 (IO_L1P_T0_D00_MOSI_14)
/FPGA Config/DO1: R905.2, U401.R22 (IO_L1N_T0_D01_DIN_14)
/FPGA Config/DO2: R904.2, U401.P21 (IO_L2P_T0_D02_14)
/FPGA Config/DO3: R906.2, U401.R21 (IO_L2N_T0_D03_14)
/FPGA Config/DONE: D901.2 (A), R916.2, U401.G11 (DONE_0)
/FPGA Config/INIT_B: R915.2, U401.U12 (INIT_B_0)
/FPGA Config/M0: R901.2, R902.1, U401.U11 (M0_0)
/FPGA Config/M1: R907.2, R908.1, U401.U10 (M1_0)
/FPGA Config/M2: R912.2, R913.1, U401.U9 (M2_0)
/FPGA Config/PROGRAM_B: R917.2, SW901.1, U401.N12 (PROGRAM_B_0)
/FPGA Config/PUDC_B: R918.2, R919.1, U401.U22 (IO_L3P_T0_DQS_PUDC_B_14)
/FPGA Config/QSPI_CLK: U401.L12 (CCLK_0), U901.6 (SCK)
/FPGA Config/QSPI_CSN: R914.2, U401.T19 (IO_L6P_T0_FCS_B_14), U901.1 (CS#)
/FPGA Config/TCK: J901.4 (TCK), U401.V12 (TCK_0)
/FPGA Config/TDI: J901.2 (TDI), U401.R13 (TDI_0)
/FPGA Config/TDO: J901.3 (TDO), U401.U13 (TDO_0)
/FPGA Config/TMS: J901.1 (TMS), U401.T13 (TMS_0)
GND: C901.2, D901.1 (K), J901.5 (GND), R902.2, R908.2, R913.2, R919.2, SW901.2, U401.L9 (VREFN_0), U401.M10 (VREFP_0), U401.N9 (DXN_0), U401.N10 (DXP_0), U901.4 (VSS), U901.9 (VSS); also elsewhere on the board
unnamed: R903.1, U901.5 (SI/IO0)
unnamed: R904.1, R910.2, U901.3 (WP#/IO2)
unnamed: R905.1, R909.2, U901.2 (SO/IO1)
unnamed: R906.1, R911.2, U901.7 (HOLD#/IO3)

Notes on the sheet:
Master SPI Mode

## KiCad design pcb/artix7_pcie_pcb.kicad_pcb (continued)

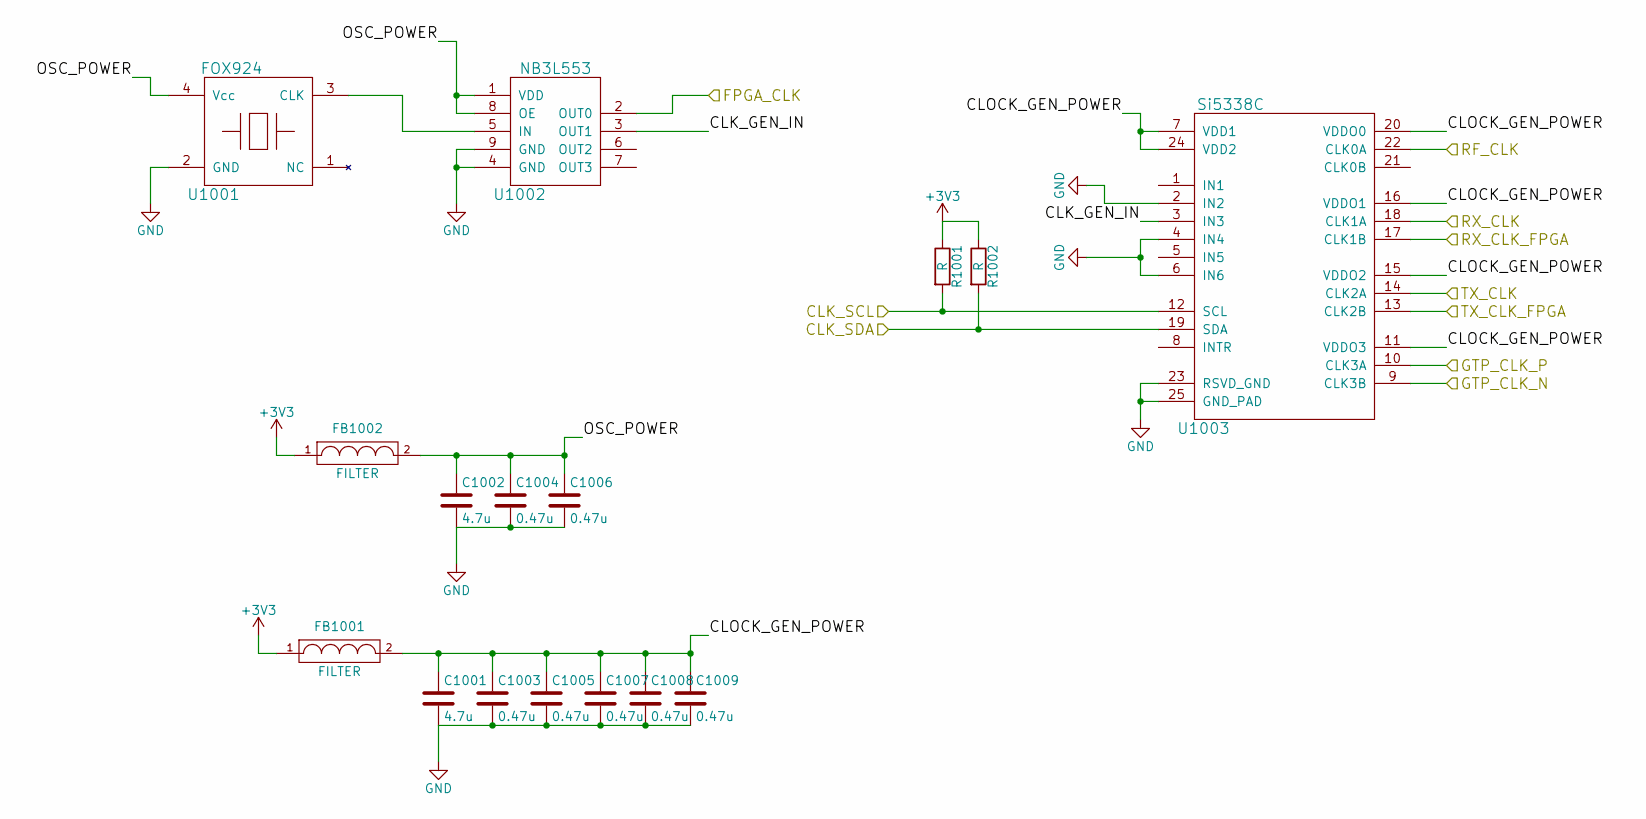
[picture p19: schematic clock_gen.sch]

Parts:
C1001, C1002: 4.7u; C_0402
C1003, C1004, C1005, C1006, C1007, C1008, C1009: 0.47u; C_0402
FB1001, FB1002: FILTER; L_0603
R1001, R1002: R; R_0402
U1001: FOX924; OSCILLATOR_5.0X3.2
U1002: NB3L553; DFN-8_2x2mm_Pitch0.5mm
U1003: Si5338C; QFN-24-1EP_4x4mm_Pitch0.5mm

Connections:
+3V3: FB1001.1, FB1002.1, R1001.1, R1002.1; also elsewhere on the board
/Clocking/CLK_GEN_IN: U1002.3 (OUT1), U1003.3 (IN3)
/Clocking/CLK_SCL: R1001.2, U1003.12 (SCL); also elsewhere on the board
/Clocking/CLK_SDA: R1002.2, U1003.19 (SDA); also elsewhere on the board
/Clocking/CLOCK_GEN_POWER: C1001.1, C1003.1, C1005.1, C1007.1, C1008.1, C1009.1, FB1001.2, U1003.7 (VDD1), U1003.11 (VDDO3), U1003.15 (VDDO2), U1003.16 (VDDO1), U1003.20 (VDDO0), U1003.24 (VDD2)
/Clocking/FPGA_CLK: U1002.2 (OUT0); also elsewhere on the board
/Clocking/GTP_CLK_N: U1003.9 (CLK3B); also elsewhere on the board
/Clocking/GTP_CLK_P: U1003.10 (CLK3A); also elsewhere on the board
/Clocking/OSC_POWER: C1002.1, C1004.1, C1006.1, FB1002.2, U1001.4 (Vcc), U1002.1 (VDD), U1002.8 (OE)
/Clocking/RF_CLK: U1003.22 (CLK0A); also elsewhere on the board
/Clocking/RX_CLK: U1003.18 (CLK1A); also elsewhere on the board
/Clocking/RX_CLK_FPGA: U1003.17 (CLK1B); also elsewhere on the board
/Clocking/TX_CLK: U1003.14 (CLK2A); also elsewhere on the board
/Clocking/TX_CLK_FPGA: U1003.13 (CLK2B); also elsewhere on the board
GND: C1001.2, C1002.2, C1003.2, C1004.2, C1005.2, C1006.2, C1007.2, C1008.2, C1009.2, U1001.2 (GND), U1002.4 (GND), U1002.9 (GND), U1003.2 (IN2), U1003.4 (IN4), U1003.6 (IN6), U1003.23 (RSVD_GND), U1003.25 (GND_PAD); also elsewhere on the board
unnamed: U1001.3 (CLK), U1002.5 (IN)

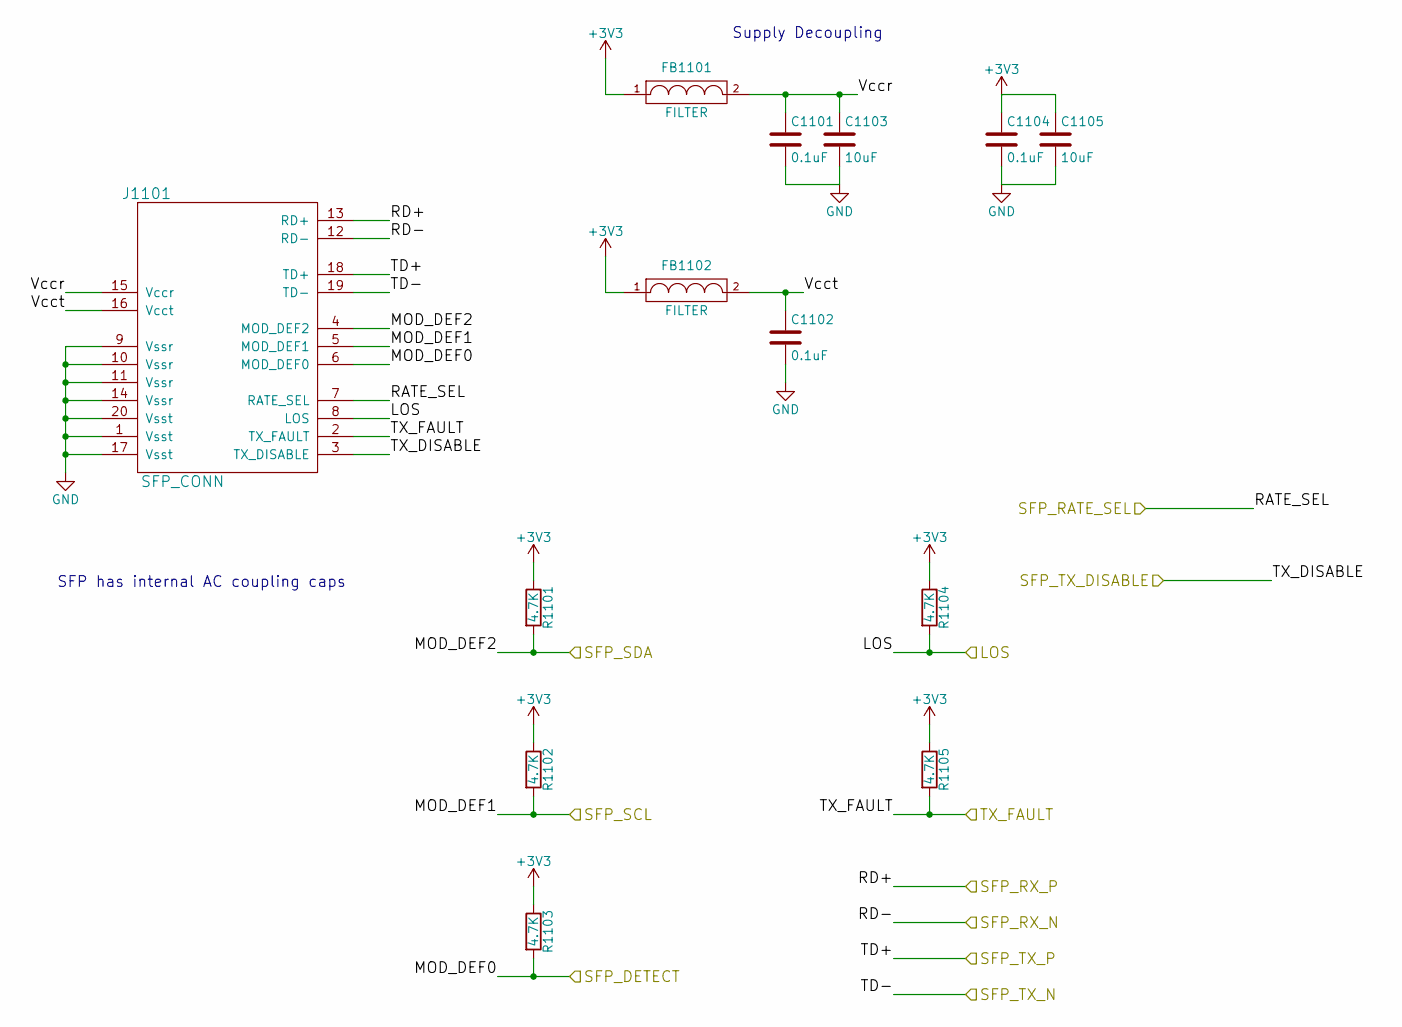
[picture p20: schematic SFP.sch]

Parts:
C1101, C1102, C1104: 0.1uF; C_0402
C1103, C1105: 10uF; C_0402
FB1101, FB1102: FILTER; L_0603
J1101: SFP_CONN; CONN-SFP_1367073-1
R1101, R1102, R1103, R1104, R1105: 4.7K; R_0402

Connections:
+3V3: C1104.1, C1105.1, FB1101.1, FB1102.1, R1101.1, R1102.1, R1103.1, R1104.1, R1105.1; also elsewhere on the board
/FPGA Transceivers/SFP_RX_N: J1101.12 (RD-); also elsewhere on the board
/FPGA Transceivers/SFP_RX_P: J1101.13 (RD+); also elsewhere on the board
/FPGA Transceivers/SFP_TX_N: J1101.19 (TD-); also elsewhere on the board
/FPGA Transceivers/SFP_TX_P: J1101.18 (TD+); also elsewhere on the board
/MyriadRF IO/SFP_DETECT: J1101.6 (MOD_DEF0), R1103.2; also elsewhere on the board
/MyriadRF IO/SFP_RATE_SEL: J1101.7 (RATE_SEL); also elsewhere on the board
/MyriadRF IO/SFP_SCL: J1101.5 (MOD_DEF1), R1102.2; also elsewhere on the board
/MyriadRF IO/SFP_SDA: J1101.4 (MOD_DEF2), R1101.2; also elsewhere on the board
/MyriadRF IO/SFP_TX_DISABLE: J1101.3 (TX_DISABLE); also elsewhere on the board
/MyriadRF IO/SFP_TX_FAULT: J1101.2 (TX_FAULT), R1105.2; also elsewhere on the board
/SFP/LOS: J1101.8 (LOS), R1104.2; also elsewhere on the board
/SFP/Vccr: C1101.1, C1103.1, FB1101.2, J1101.15 (Vccr)
/SFP/Vcct: C1102.1, FB1102.2, J1101.16 (Vcct)
GND: C1101.2, C1102.2, C1103.2, C1104.2, C1105.2, J1101.1 (Vsst), J1101.9 (Vssr), J1101.10 (Vssr), J1101.11 (Vssr), J1101.14 (Vssr), J1101.17 (Vsst), J1101.20 (Vsst); also elsewhere on the board

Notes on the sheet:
Supply Decoupling
SFP has internal AC coupling caps

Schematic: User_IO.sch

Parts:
D1201, D1202, D1203, D1204: LED; LED-0805
P1201, P1202: CONN_02X05; Pin_Header_Straight_2x05
R1201, R1202, R1203, R1204, R1207, R1208: R; R_0402
SW1201, SW1202: SW_PUSH; button-5mm
U401: XC7Axxt-FGG484; BGA_484_22x22_FULLARRAY_1MM

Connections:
+3V3: P1201.9, P1202.9, R1207.2, R1208.2; also elsewhere on the board
/User IO/B0: R1208.1, SW1202.1, U401.T1 (IO_L1P_T0_34)
/User IO/B1: R1207.1, SW1201.1, U401.U1 (IO_L1N_T0_34)
/User IO/IO0: P1201.1, U401.V4 (IO_L12P_T1_MRCC_34)
/User IO/IO1: P1201.2, U401.AA4 (IO_L11N_T1_SRCC_34)
/User IO/IO2: P1201.3, U401.Y4 (IO_L11P_T1_SRCC_34)
/User IO/IO3: P1201.4, U401.W4 (IO_L12N_T1_MRCC_34)
/User IO/IO4: P1201.5, U401.AB3 (IO_L8P_T1_34)
/User IO/IO5: P1201.6, U401.AA3 (IO_L9N_T1_DQS_34)
/User IO/IO6: P1201.7, U401.Y3 (IO_L9P_T1_DQS_34)
/User IO/IO7: P1201.8, U401.AB2 (IO_L8N_T1_34)
/User IO/IO8: P1202.1, U401.R4 (IO_L13P_T2_MRCC_34)
/User IO/IO9: P1202.2, U401.R3 (IO_L3P_T0_DQS_34)
/User IO/IO10: P1202.3, U401.AB1 (IO_L7N_T1_34)
/User IO/IO11: P1202.4, U401.AA1 (IO_L7P_T1_34)
/User IO/IO12: P1202.5, U401.Y2 (IO_L4N_T0_34)
/User IO/IO13: P1202.6, U401.Y1 (IO_L5N_T0_34)
/User IO/IO14: P1202.7, U401.W2 (IO_L4P_T0_34)
/User IO/IO15: P1202.8, U401.W1 (IO_L5P_T0_34)
/User IO/LED0: R1201.2, U401.U2 (IO_L2P_T0_34)
/User IO/LED1: R1202.2, U401.V2 (IO_L2N_T0_34)
/User IO/LED2: R1203.2, U401.U3 (IO_L6P_T0_34)
/User IO/LED3: R1204.2, U401.V3 (IO_L6N_T0_VREF_34)
/User IO/PCIE_PERST: U401.R6 (IO_L17P_T2_34); also elsewhere on the board
GND: D1201.1 (K), D1202.1 (K), D1203.1 (K), D1204.1 (K), P1201.10, P1202.10, SW1201.2, SW1202.2; also elsewhere on the board
unnamed: D1201.2 (A), R1201.1
unnamed: D1202.2 (A), R1202.1
unnamed: D1203.2 (A), R1203.1
unnamed: D1204.2 (A), R1204.1

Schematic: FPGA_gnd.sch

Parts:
U401: XC7Axxt-FGG484; BGA_484_22x22_FULLARRAY_1MM

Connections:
GND: U401.A2 (GND), U401.A3 (GND), U401.A5 (GND), U401.A7 (GND), U401.A9 (GND), U401.A11 (GND), U401.A12 (GND), U401.A22 (GND), U401.AA2 (GND), U401.AA12 (GND), U401.AA22 (GND), U401.AB9 (GND), U401.AB19 (GND), U401.B3 (GND), U401.B12 (GND), U401.B19 (GND), U401.C3 (GND), U401.C6 (GND), U401.C10 (GND), U401.C12 (GND), U401.C16 (GND), U401.D3 (GND), U401.D4 (GND), U401.D8 (GND), U401.D12 (GND), U401.D13 (GND), U401.E4 (GND), U401.E5 (GND), U401.E7 (GND), U401.E9 (GND), U401.E11 (GND), U401.E20 (GND), U401.F5 (GND), U401.F11 (GND), U401.F17 (GND), U401.G5 (GND), U401.G6 (GND), U401.G7 (GND), U401.G8 (GND), U401.G9 (GND), U401.G10 (GND), U401.G12 (GND), U401.G14 (GND), U401.H1 (GND), U401.H7 (GND), U401.H9 (GND), U401.H11 (GND), U401.H21 (GND), U401.J8 (GND), U401.J10 (GND), U401.J12 (GND), U401.J18 (GND), U401.K5 (GND), U401.K7 (GND), U401.K9 (GNDADC), U401.K11 (GND), U401.K15 (GND), U401.L2 (GND), U401.L8 (GND), U401.L22 (GND), U401.M7 (GND), U401.M11 (GND), U401.M19 (GND), U401.N6 (GND), U401.N8 (GND), U401.N16 (GND), U401.P3 (GND), U401.P7 (GND), U401.P9 (GND), U401.P11 (GND), U401.P13 (GND), U401.R8 (GND), U401.R10 (GND), U401.R12 (GND), U401.R20 (GND), U401.T7 (GND), U401.T9 (GND), U401.T11 (GND), U401.T17 (GND), U401.U4 (GND), U401.U14 (GND), U401.V1 (GND), U401.V11 (GND), U401.V21 (GND), U401.W8 (GND), U401.W18 (GND), U401.Y5 (GND), U401.Y15 (GND); also elsewhere on the board

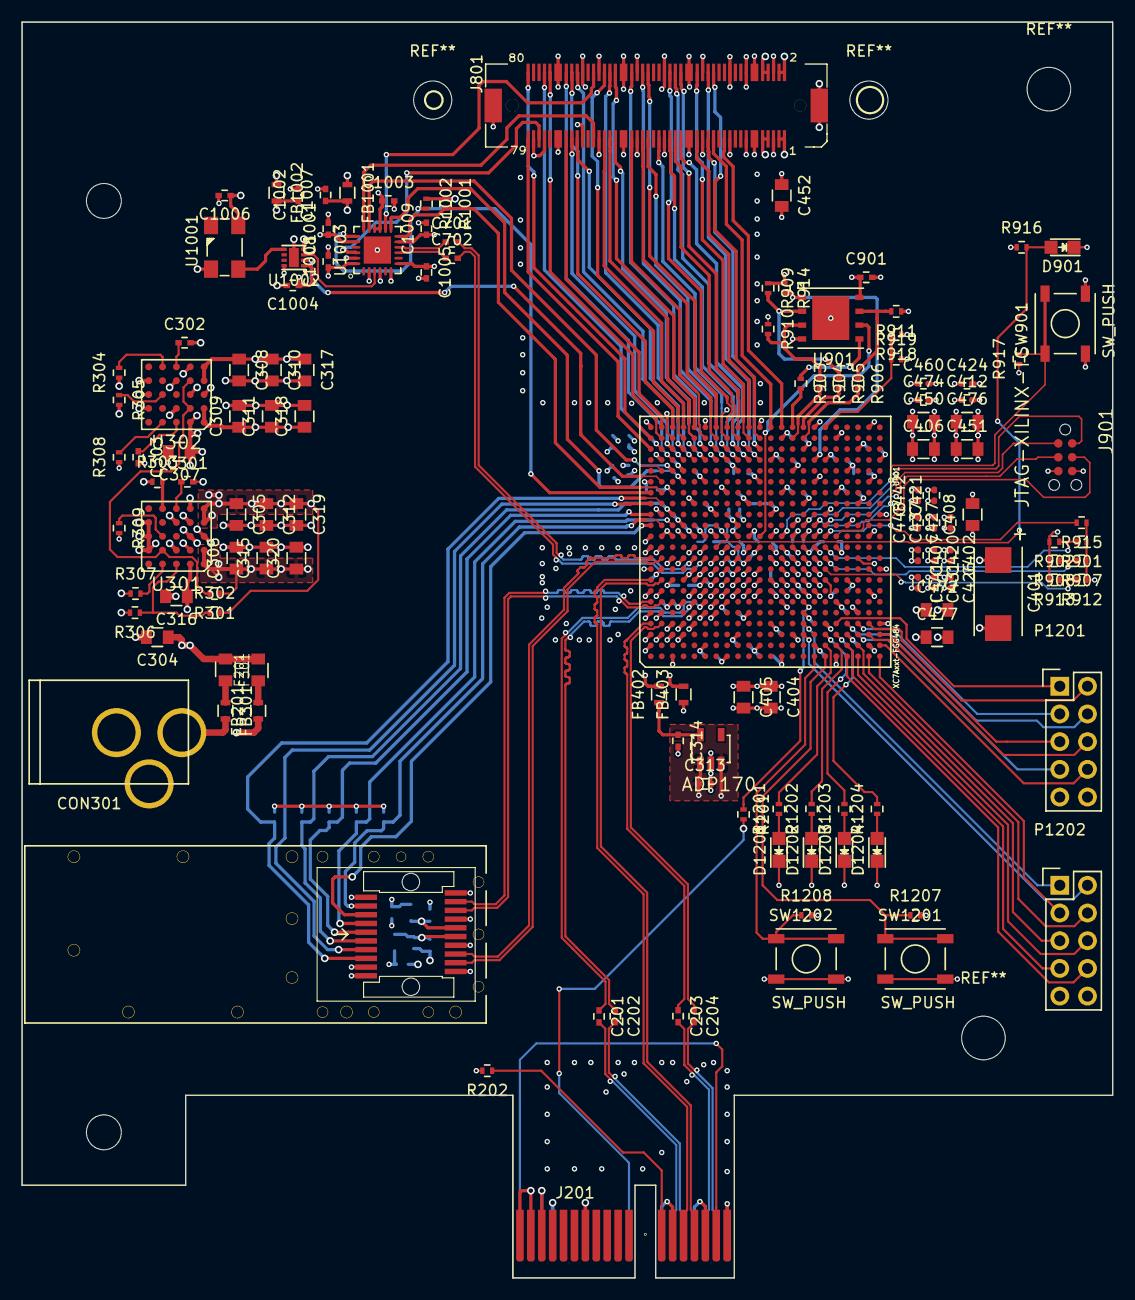
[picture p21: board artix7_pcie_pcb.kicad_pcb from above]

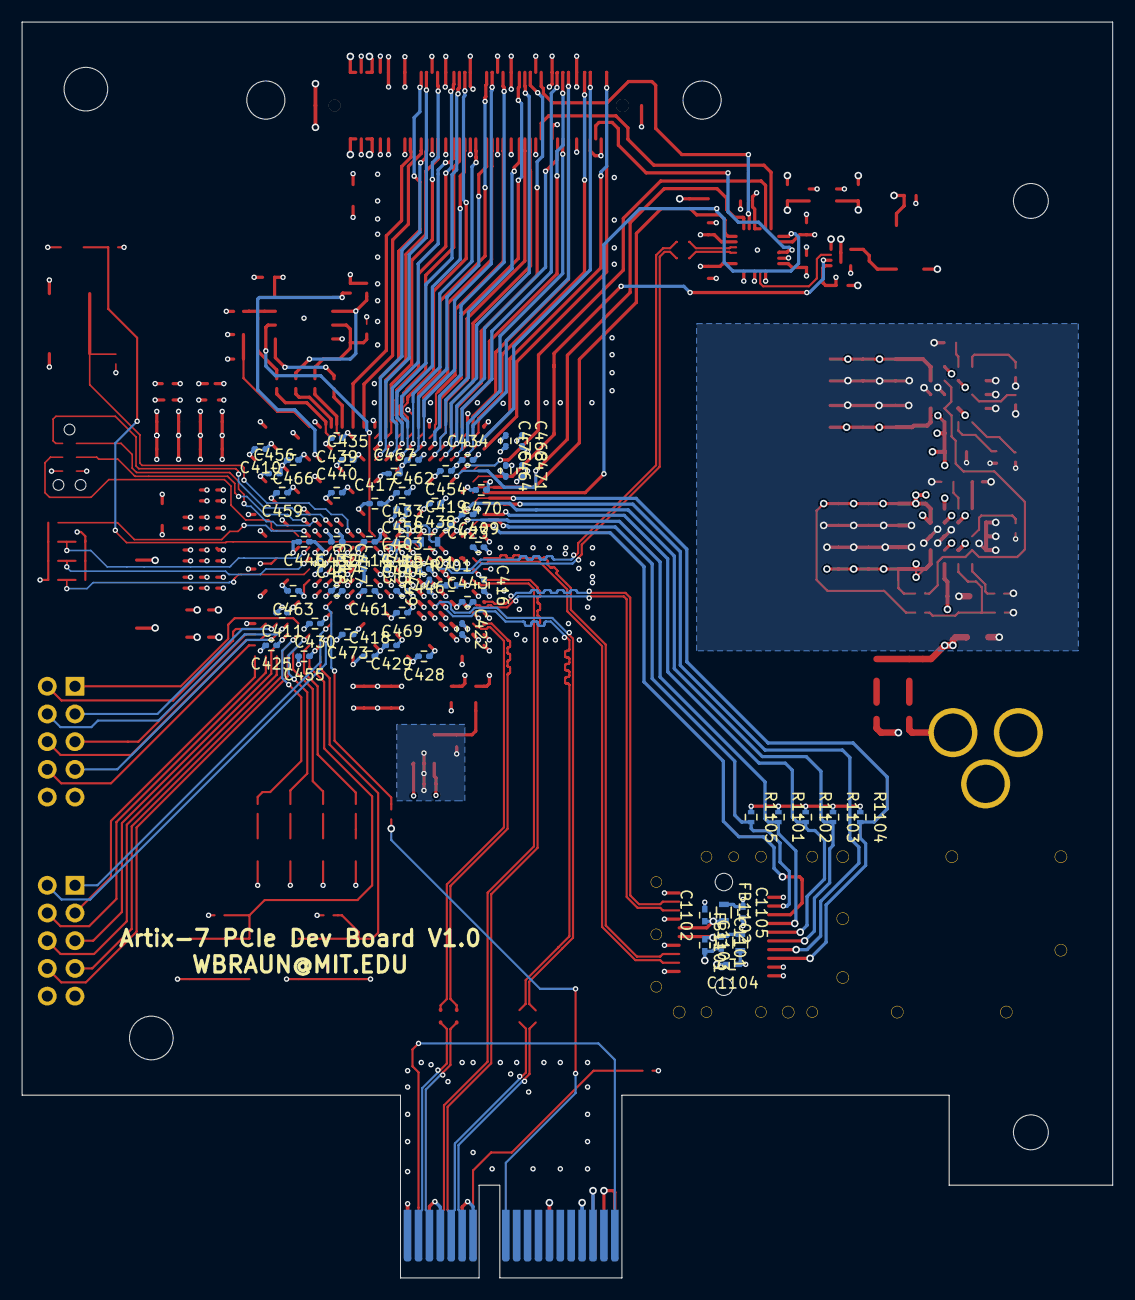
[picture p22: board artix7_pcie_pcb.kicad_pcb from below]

Board: 4 copper layers, 100.0 x 115.2 mm, 197 parts (65 on the bottom side), 152 nets.

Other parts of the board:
CONN-SFP-CAGE: VAL**; CONN-SFP-CAGE

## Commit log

2015-10-13 power pages done
    [DDR3.sch, DDR3_power.sch, FPGA_transceivers.sch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]
2015-11-21 worked on configuration
    [DDR3.sch, DDR3_power.sch, FPGA_transceivers.sch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]
2015-11-21 added new files
    [FPGA_Config.sch, MyriadRF_power.sch, clock_gen.sch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]
2015-12-03 schematic completed. Time for review
    [DDR3.sch, DDR3_power.sch, FPGA_Config.sch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]
2015-12-03 Added part numbers and updated schematic
    [DDR3.sch, DDR3_power.sch, FPGA_Config.sch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]
2015-12-05 mostly done with component placement
    [DDR3.sch, DDR3_power.sch, FPGA_Config.sch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]
2015-12-06 Finished initial component placement
    [User_IO.sch, artix7_pcie_pcb.kicad_pcb]
2015-12-07 DDR routing test 1
    [DDR3.sch, DDR3_power.sch, FPGA_Config.sch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]
2015-12-21 Finished most of the routing, removed DDR-3
    [FPGA_Config.sch, FPGA_gnd.sch, FPGA_transceivers.sch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]
2015-12-22 power routing finished
    [FPGA_Config.sch, FPGA_gnd.sch, User_IO.sch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]
2015-12-23 routing finished, need final check
    [FPGA_Config.sch, User_IO.sch, _saved_SFP.sch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]
2015-12-24 Pending final check
    [FPGA_Config.sch, FPGA_gnd.sch, FPGA_transceivers.sch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]
2015-12-25 Ready for fab
    [FPGA_Config.sch, FPGA_gnd.sch, FPGA_transceivers.sch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]
2015-12-27 generated gerbers
    [artix7_pcie_pcb-B.Cu.gbl, artix7_pcie_pcb-B.Mask.gbs, artix7_pcie_pcb-B.SilkS.gbo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]
2015-12-28 sent off PCB to fab
2015-12-28 sent of PCB to fab
2016-01-30 updated schematic, stencil
    [_saved_power_rails.sch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]
